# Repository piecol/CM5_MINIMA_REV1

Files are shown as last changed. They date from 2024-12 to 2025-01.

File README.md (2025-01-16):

# CM5_MINIMA_REV1
_Compact, feature-filled, CM5 LoRaWAN carrier board_

## **OSHWA**:
This project is certified as open-source hardware under the UID: IT000019
https://certification.oshwa.org/it000019.html

## **Warning**:
Board tested, everything works, except for the RAK3172 UART, which was moved from UART0_IR to UART2. It works with this change, schematics, layout and production files are corrected.

_Proceed at your own risk._

 [PDF SCHEMATICS](https://github.com/piecol/CM5_MINIMA_REV1/blob/main/CM5_MINIMA.pdf)

## **Peripherals**:
- USB-C PD (CM5 can negotiate power delivery!)
- USB2.0 
- Gigabit Ethernet with cutout magjack for low profile
- HDMI port
- RAK3172 lorawan chip from RAKwireless
- SHTC3 Sensirion temperature and humidity sensor
- I2C connector (3V3 only)
- Fan connector
- Various status LEDs
- Compact size 5.4 x 5.7 cm

## **Stackup**:
4L (SIG:PWR | GND | GND | SIG:PWR) 
JLC0416H-3313 impedance stackup

### If you would like to support me:

"Buy Me A Coffee" (https://www.buymeacoffee.com/pierluigicj)

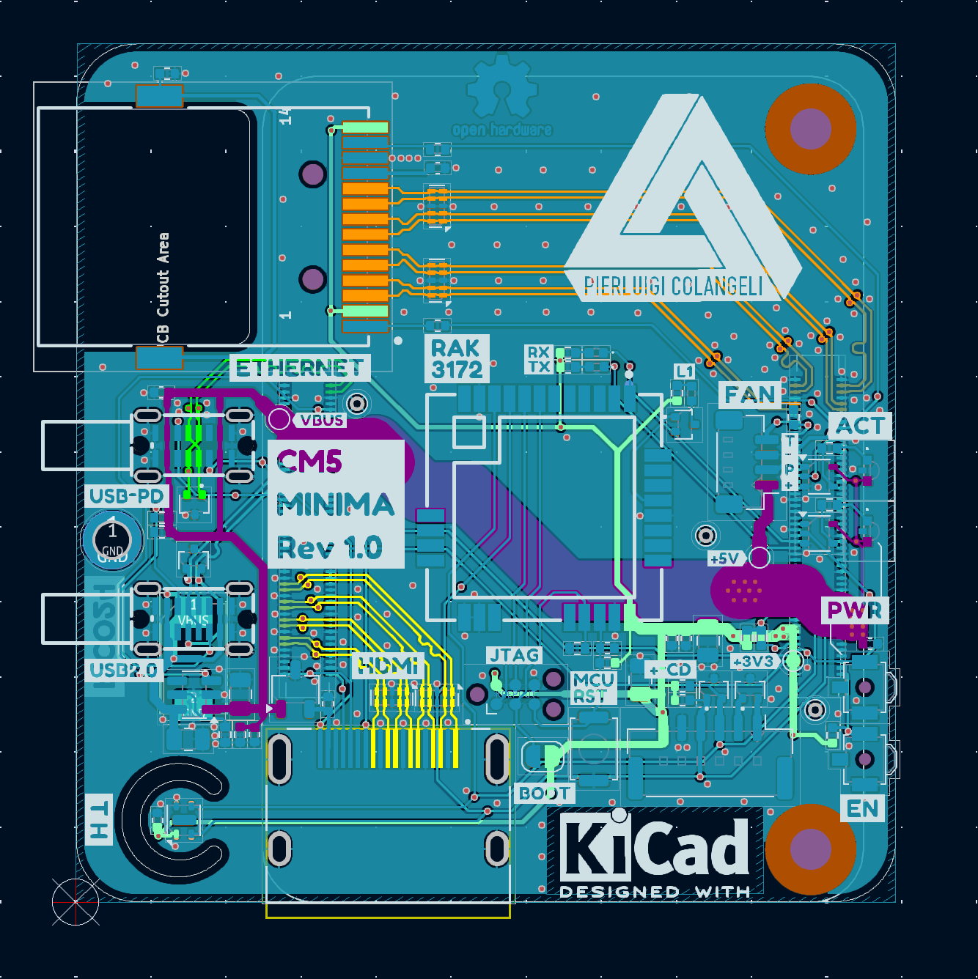
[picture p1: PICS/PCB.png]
PCB
 
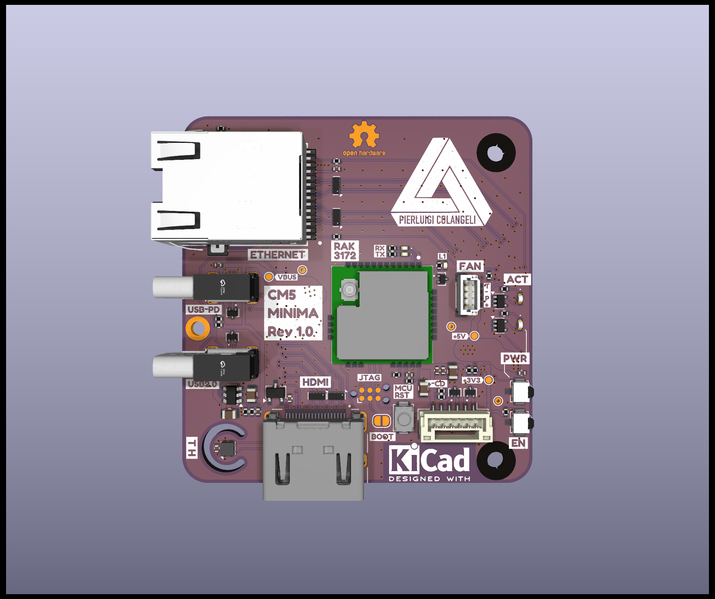
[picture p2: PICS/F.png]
F
 
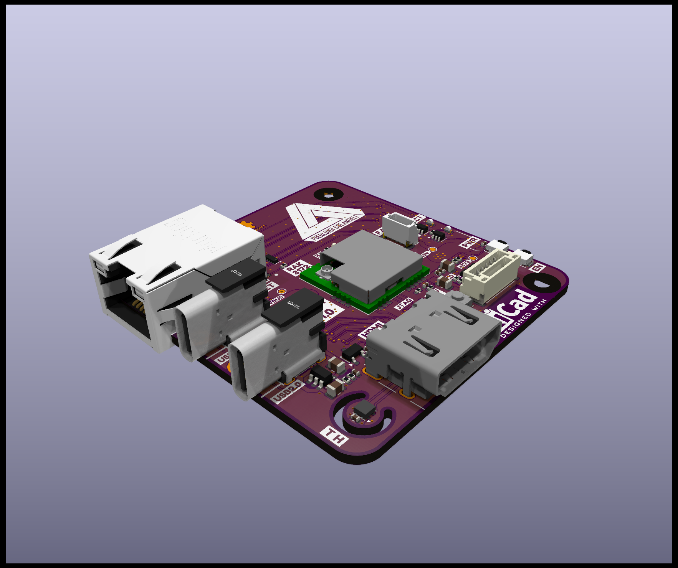
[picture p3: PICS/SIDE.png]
SIDE
 
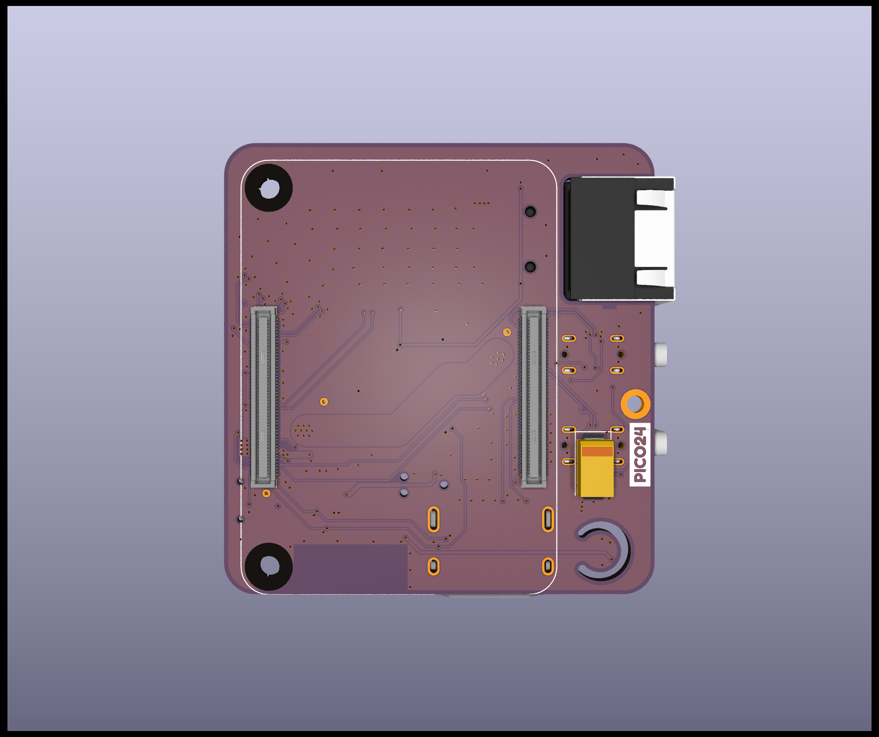
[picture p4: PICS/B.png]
B


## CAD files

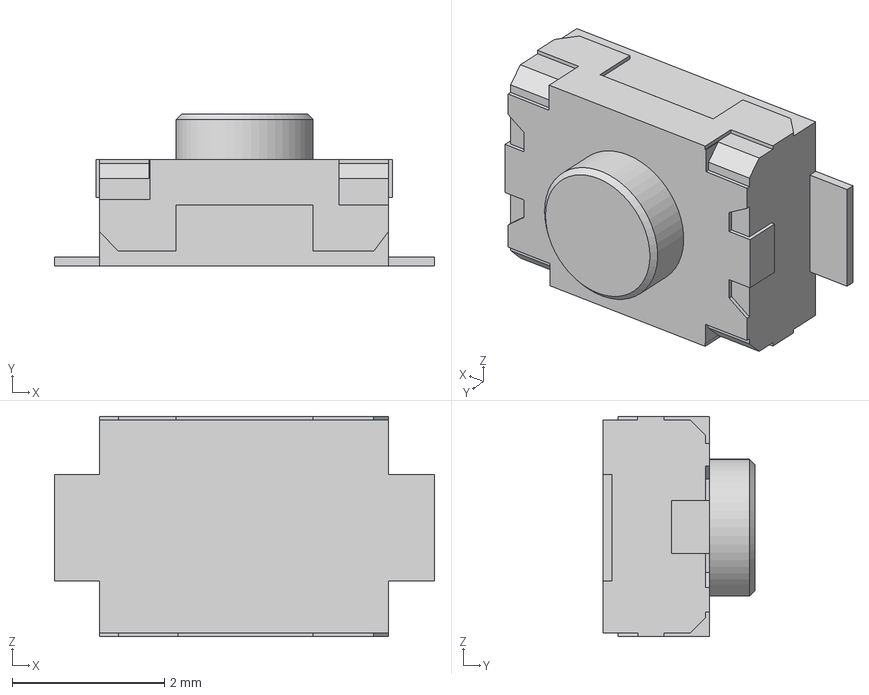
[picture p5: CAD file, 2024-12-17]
3d_lib/3x4x2 tact button.step
5.00 x 2.00 x 2.90 mm

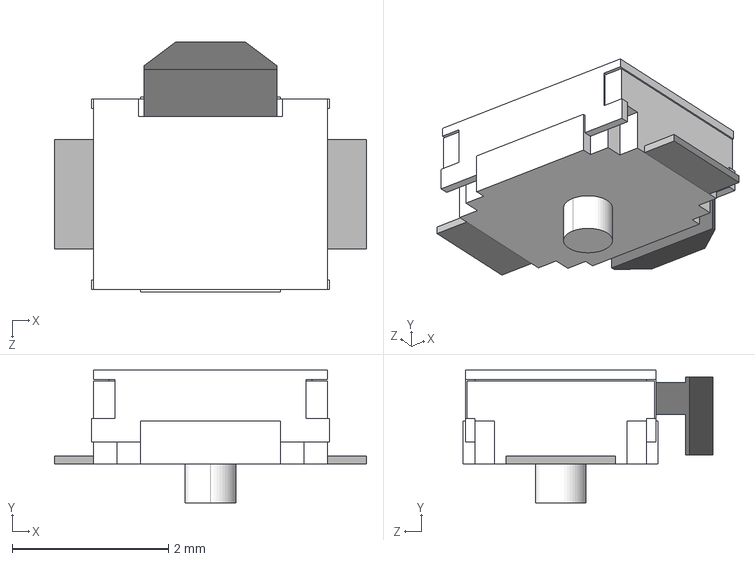
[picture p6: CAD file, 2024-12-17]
3d_lib/LIB_B3U-3000PM-B/B3U-3000PM-B/3D/B3U-3000PM-B.stp
4.00 x 1.70 x 3.20 mm

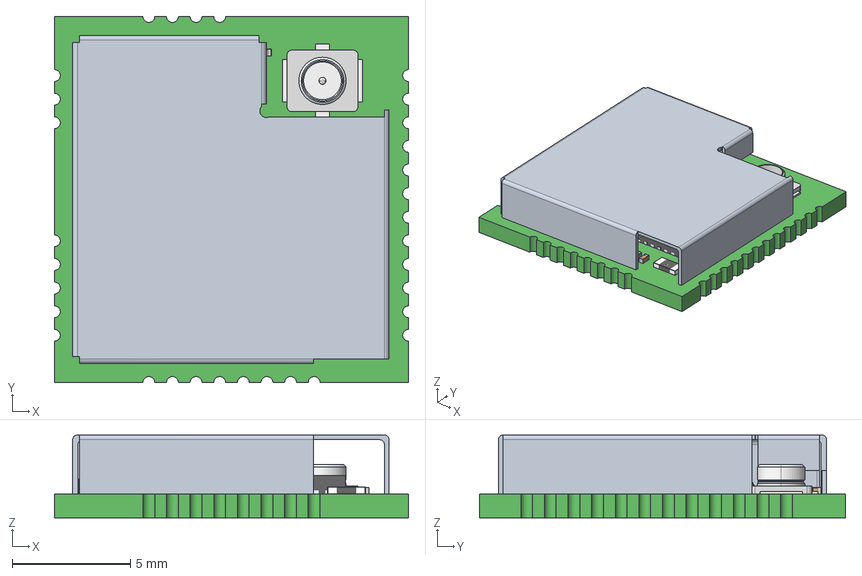
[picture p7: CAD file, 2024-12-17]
3d_lib/RAK3172--3DModel-STEP-100311.STEP
15.0 x 15.5 x 3.51 mm
0201_SMD_Capacitor x 36
Extruded
R0201 x 7
RES_1005-0402 x 3
QFN48_7x7
NT2016SA
C0402 x 4
crystal_rtf2012
D030A-そ敖裔

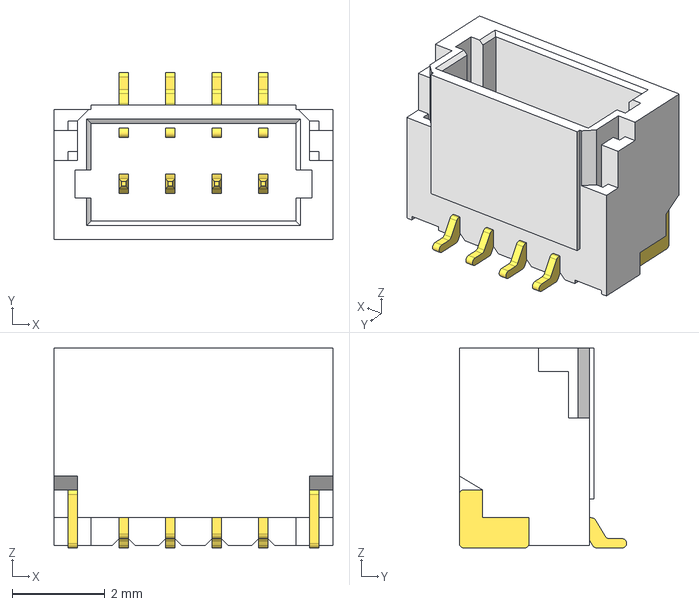
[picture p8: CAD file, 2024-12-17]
3d_lib/BM4B-SRSS-TB.step
6.00 x 3.60 x 4.30 mm

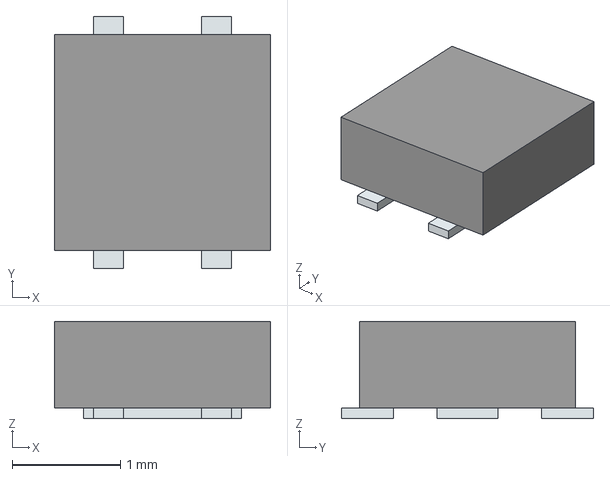
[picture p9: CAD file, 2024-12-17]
3d_lib/SHTC3-TR-10KS.stp
2.00 x 2.33 x 0.9 mm
Pins

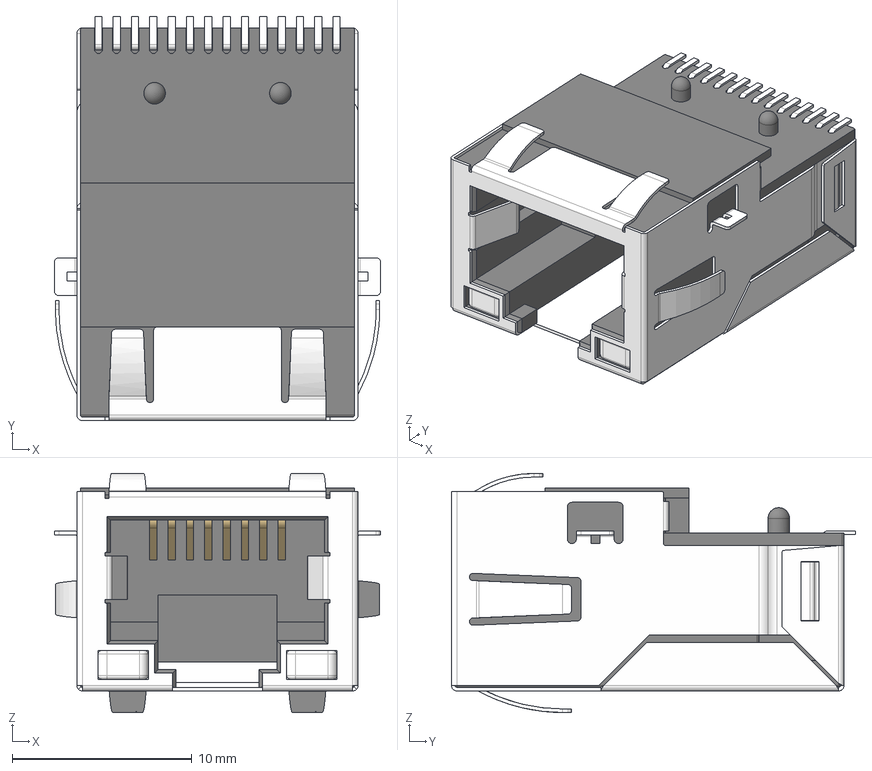
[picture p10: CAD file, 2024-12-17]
3d_lib/WE-RJ45LAN-7498111120AR (rev1).stp
18.1 x 22.5 x 13.3 mm
Shielding
Insulator x 3

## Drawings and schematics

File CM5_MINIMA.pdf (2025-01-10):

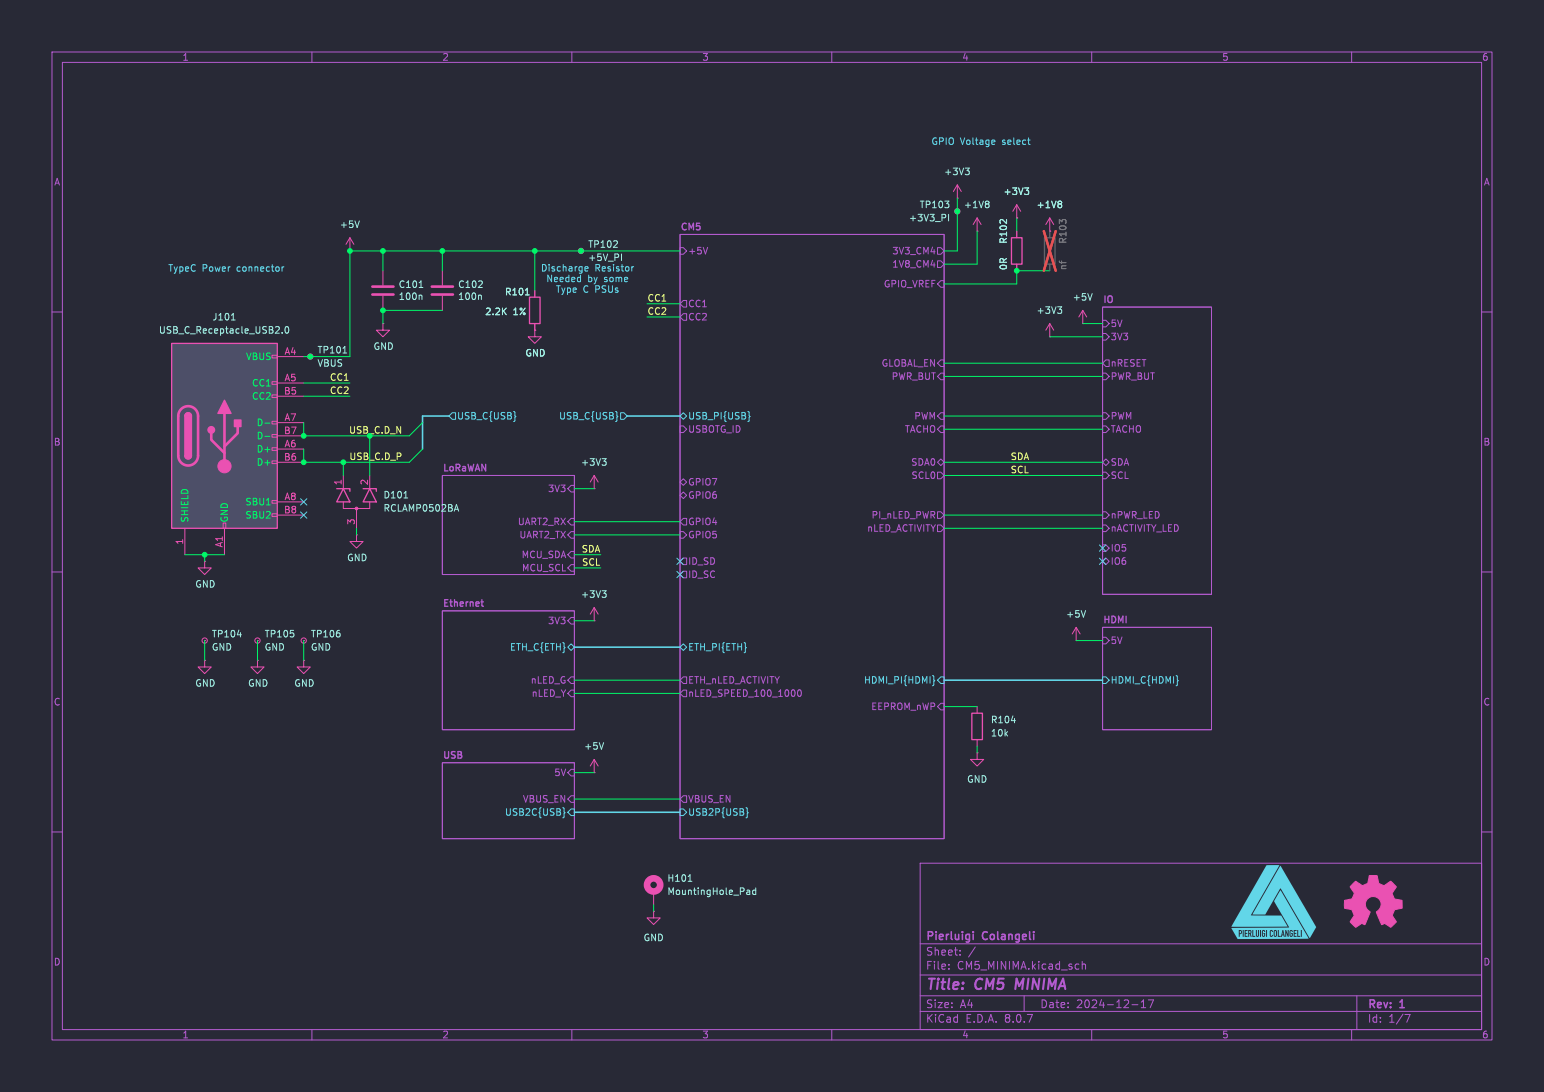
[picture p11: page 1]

File: CM5_MINIMA.kicad_sch Sheet: / Pierluigi Colangeli

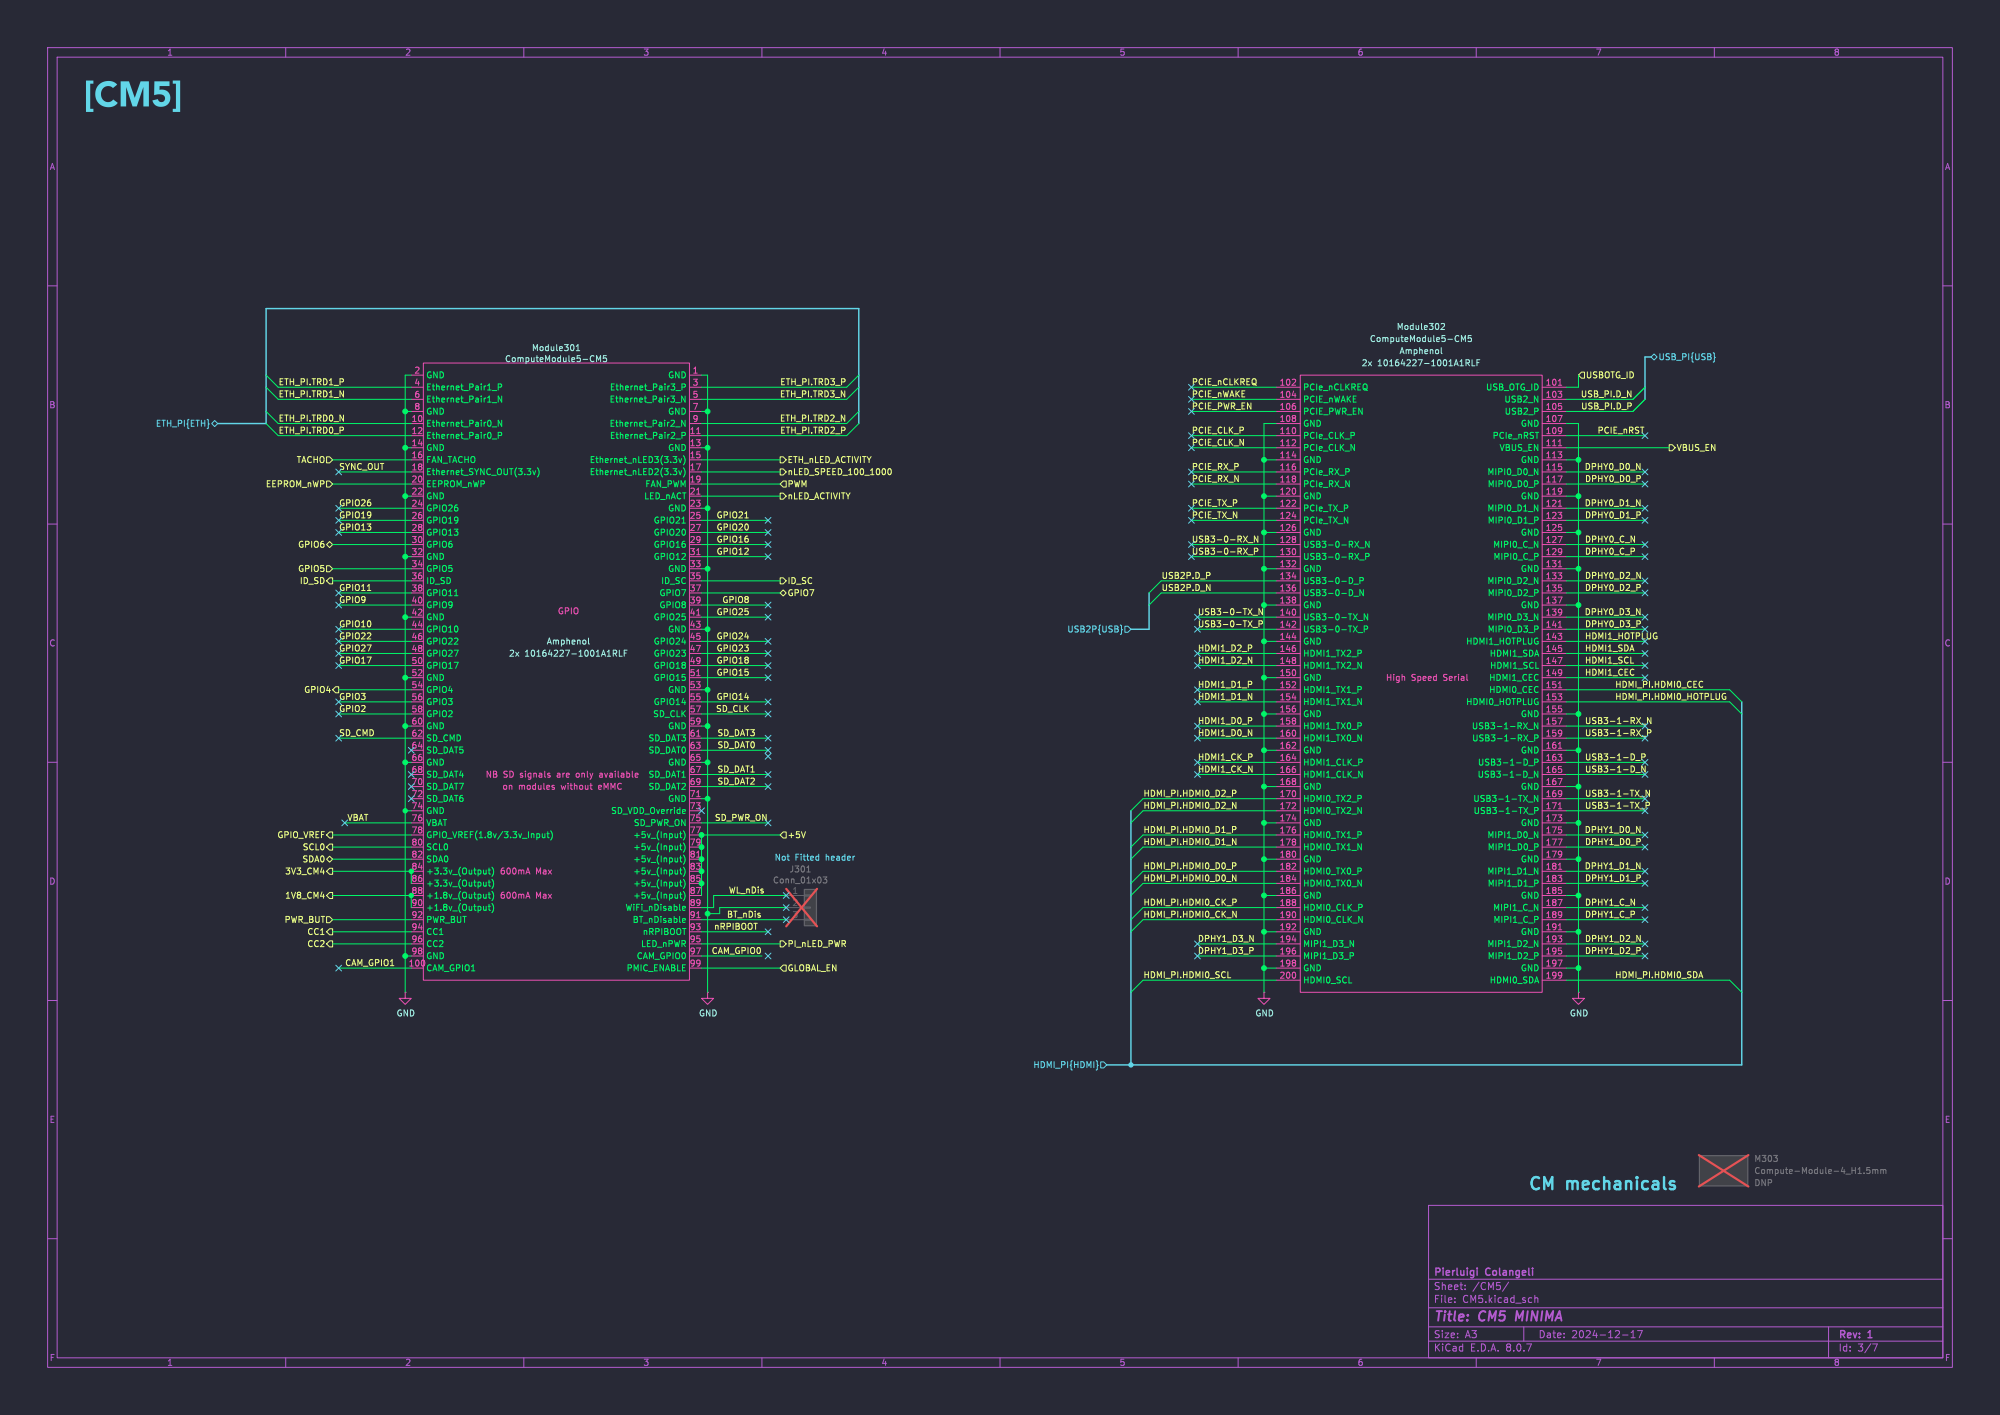
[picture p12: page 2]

600mA Max 600mA Max NB SD signals are only available

File: CM5.kicad_sch Sheet: /CM5/ Pierluigi Colangeli

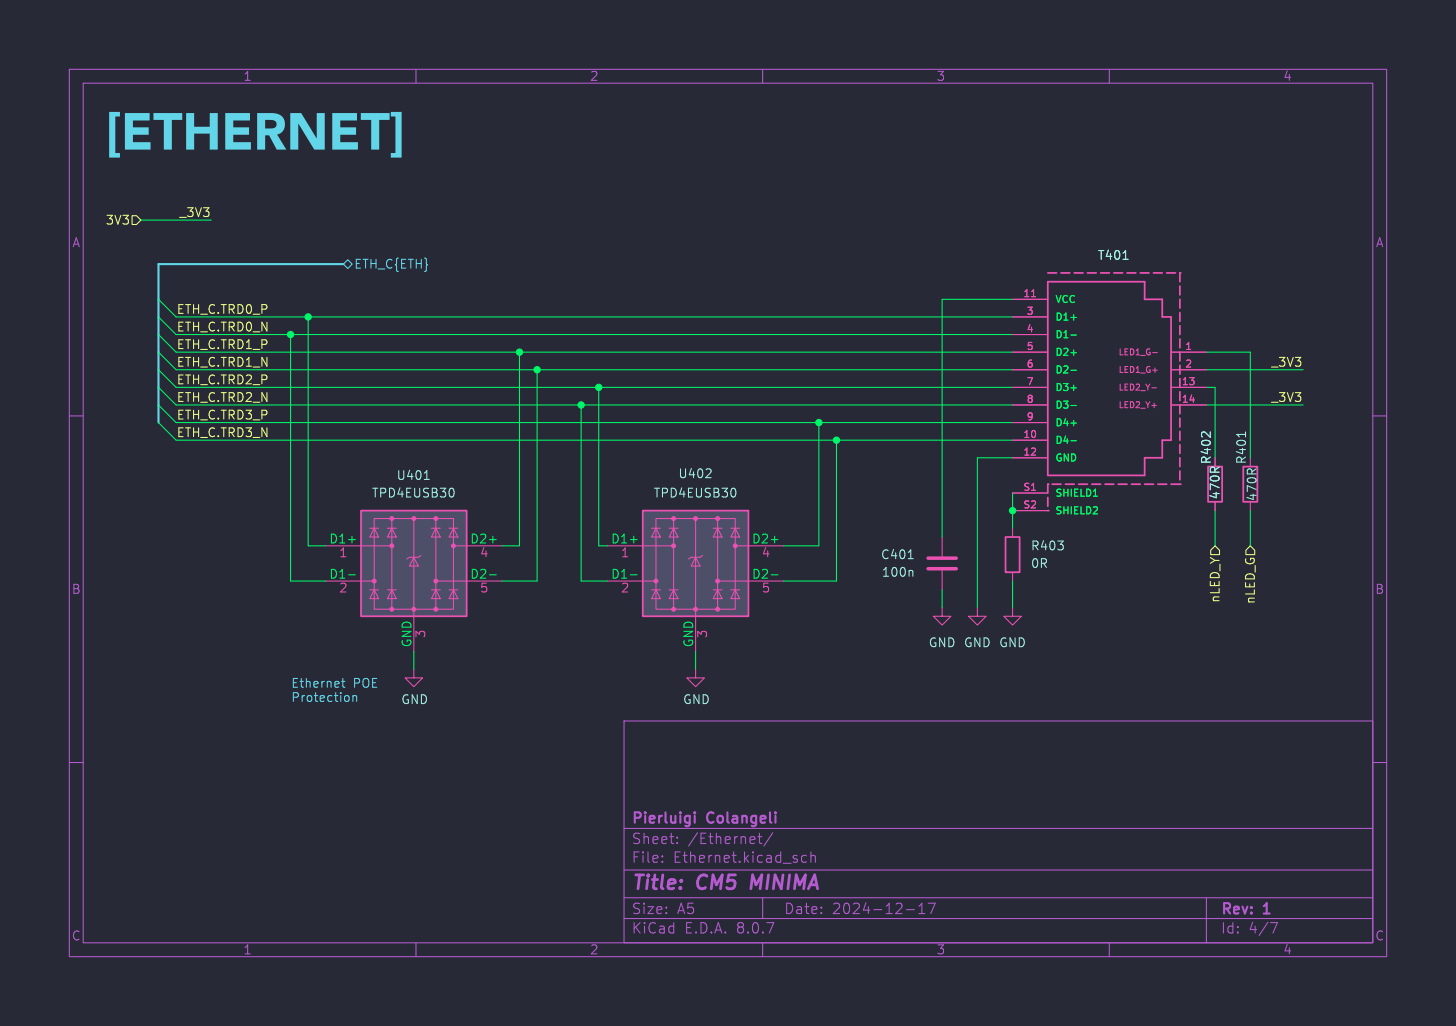
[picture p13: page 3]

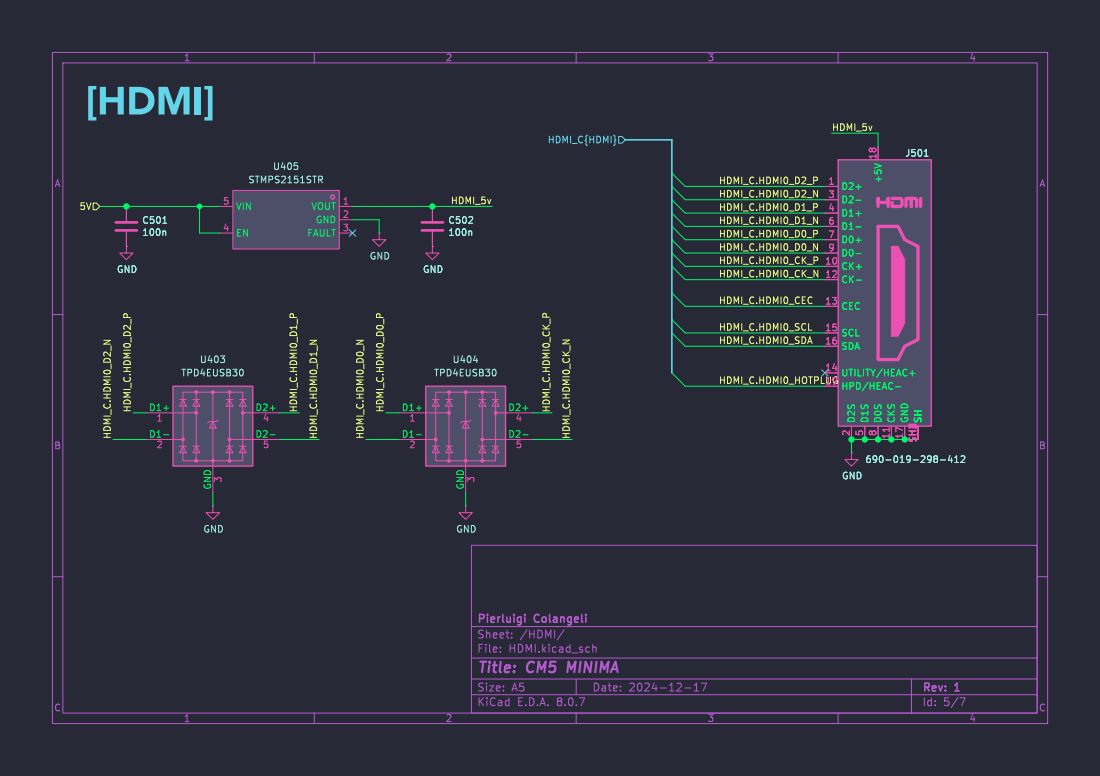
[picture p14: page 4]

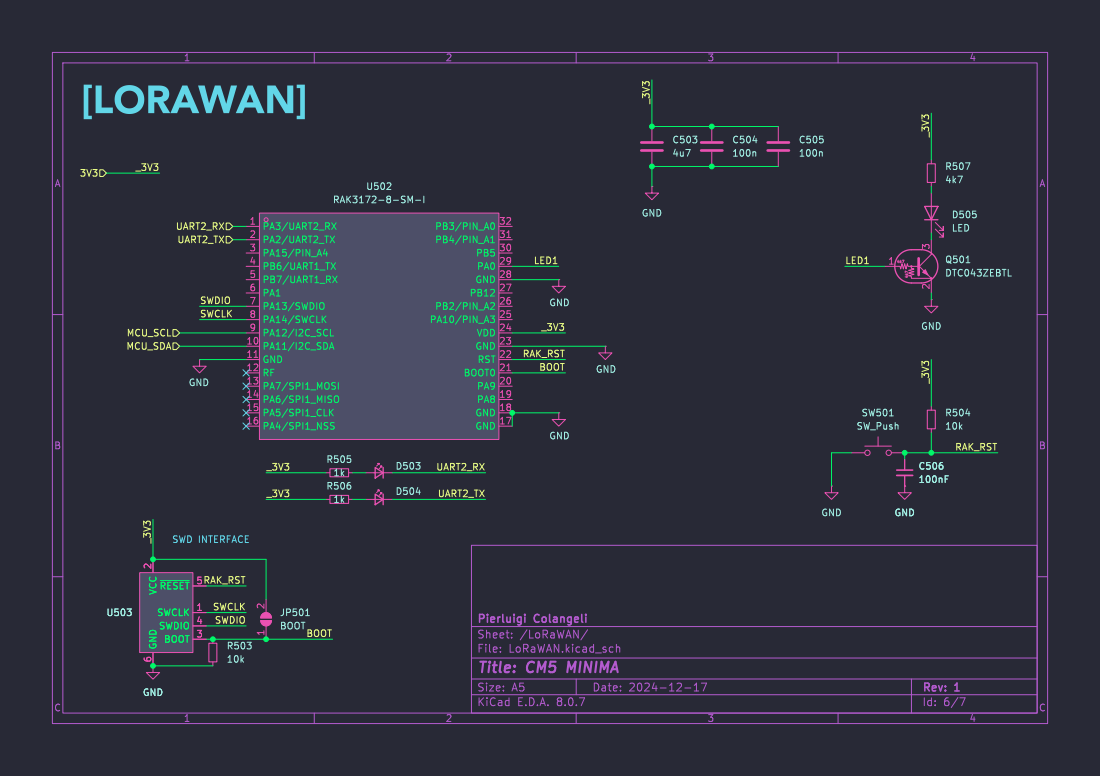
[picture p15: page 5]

2 BOOT 3 SWDIO 4 ~{RESET}5 GND

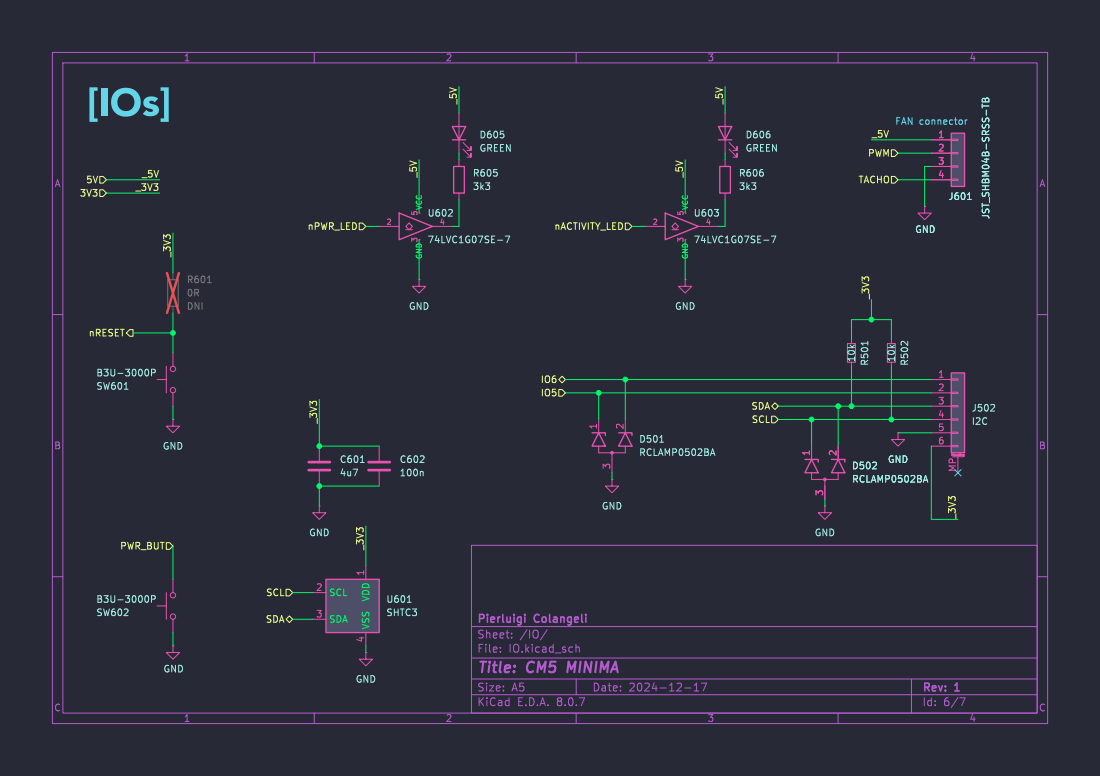
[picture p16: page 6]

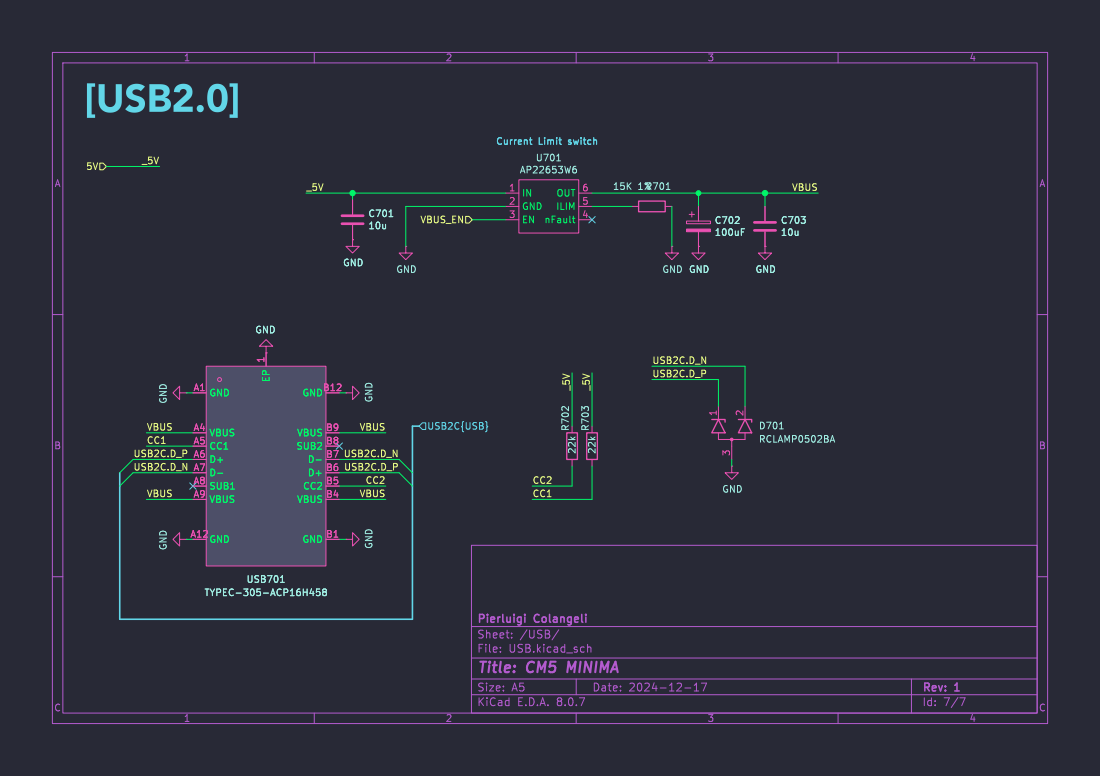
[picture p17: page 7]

1 GND A1 GND A12 VBUS A4 CC1 A5 D+ A6 D- A7 SUB1 A8 VBUS A9 GND B1 GNDB12 VBUS B4 CC2 B5 D+ B6 D- B7 SUB2 B8 VBUS B9 C701

1 GND A1 GND A12 VBUS A4 CC1 A5 D+ A6 D- A7 SUB1 A8 VBUS A9 GND B1 GNDB12 VBUS B4 CC2 B5 D+ B6 D- B7 SUB2 B8 VBUS B9 USB701 TYPEC-305-ACP16H458

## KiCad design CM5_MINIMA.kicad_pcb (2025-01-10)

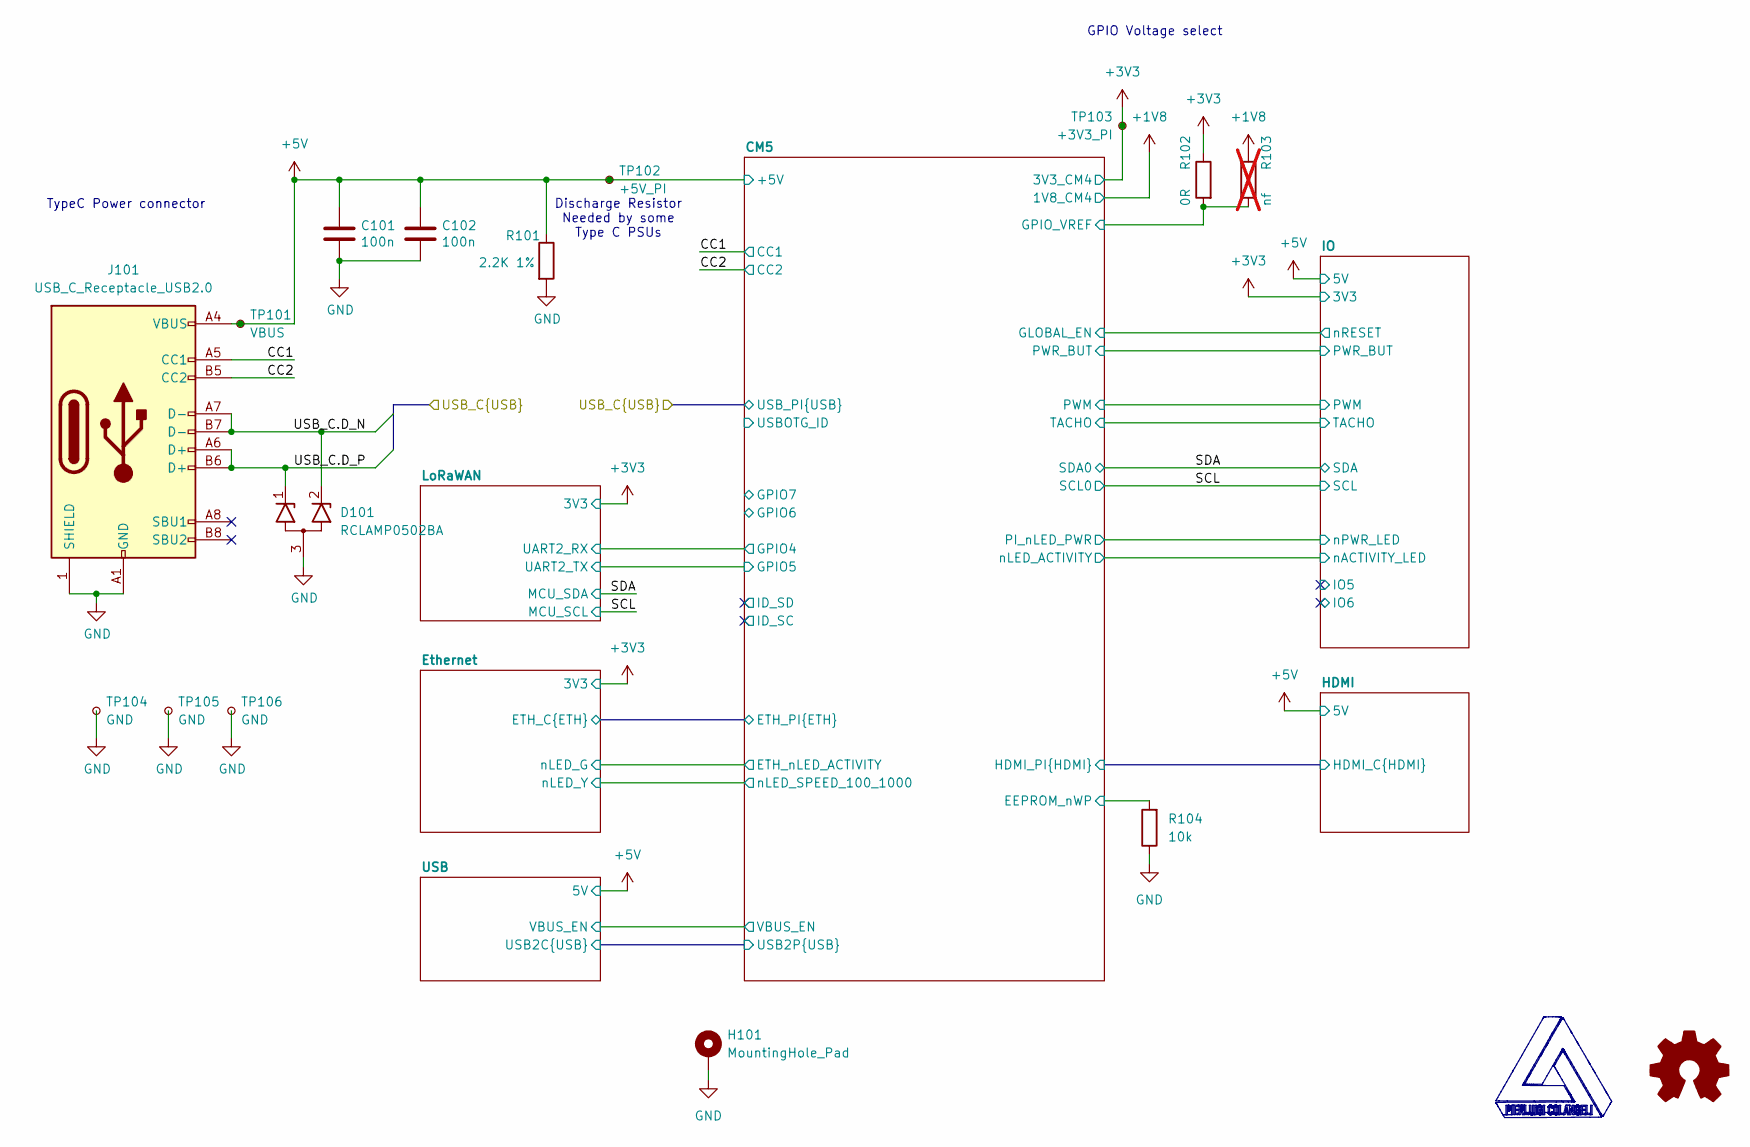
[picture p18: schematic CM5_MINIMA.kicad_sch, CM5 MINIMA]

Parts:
C101, C102: 100n; C_0402_1005Metric; Part Description 0.1uF 10% 16V Ceramic Capacitor X7R 040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
D101: RCLAMP0502BA; SOT-416
H101: MountingHole_Pad; MountingHole_2.2mm_M2_DIN965_Pad_TopBottom
J101: USB_C_Receptacle_USB2.0; USB-C-SMD_TYPEC-305-ACP16H458; Part Description USBC USB2 data and power connector
R101: 2.2K 1%; R_0402_1005Metric; Part Description Resistor 2.2K M1005 1% 63mW
R102: 0R; R_0402_1005Metric; Part Description Resistor 0R M2012 5%
R103: nf; R_0402_1005Metric; not fitted
R104: 10k; R_0402_1005Metric
TP101: VBUS; TestPoint_Pad_D1.0mm
TP102: +5V_PI; TestPoint_Pad_D1.0mm
TP103: +3V3_PI; TestPoint_Pad_D1.0mm
TP104, TP105, TP106: GND; TestPoint_THTPad_D1.0mm_Drill0.5mm

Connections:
+1V8: R103.1; also elsewhere on the board
+3V3: R102.1, TP103.1; also elsewhere on the board
+5V: C101.1, C102.1, J101.A4 (VBUS), J101.A9 (VBUS), J101.B4 (VBUS), J101.B9 (VBUS), R101.1, TP101.1, TP102.1; also elsewhere on the board
/CC1: J101.A5 (CC1); also elsewhere on the board
/CC2: J101.B5 (CC2); also elsewhere on the board
/CM5/EEPROM_nWP: R104.2; also elsewhere on the board
/CM5/GPIO_VREF: R102.2, R103.2; also elsewhere on the board
/USB_C.D_N: D101.2 (K2), J101.A7 (D-), J101.B7 (D-); also elsewhere on the board
/USB_C.D_P: D101.1 (K1), J101.A6 (D+), J101.B6 (D+); also elsewhere on the board
GND: C101.2, C102.2, D101.3 (A), H101.1, J101.1 (SHIELD), J101.A1 (GND), J101.A12 (GND), J101.B1 (GND), J101.B12 (GND), R101.2, R104.1, TP104.1, TP105.1, TP106.1; also elsewhere on the board

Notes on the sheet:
GPIO Voltage select
TypeC Power connector
Discharge Resistor Needed by some Type C PSUs

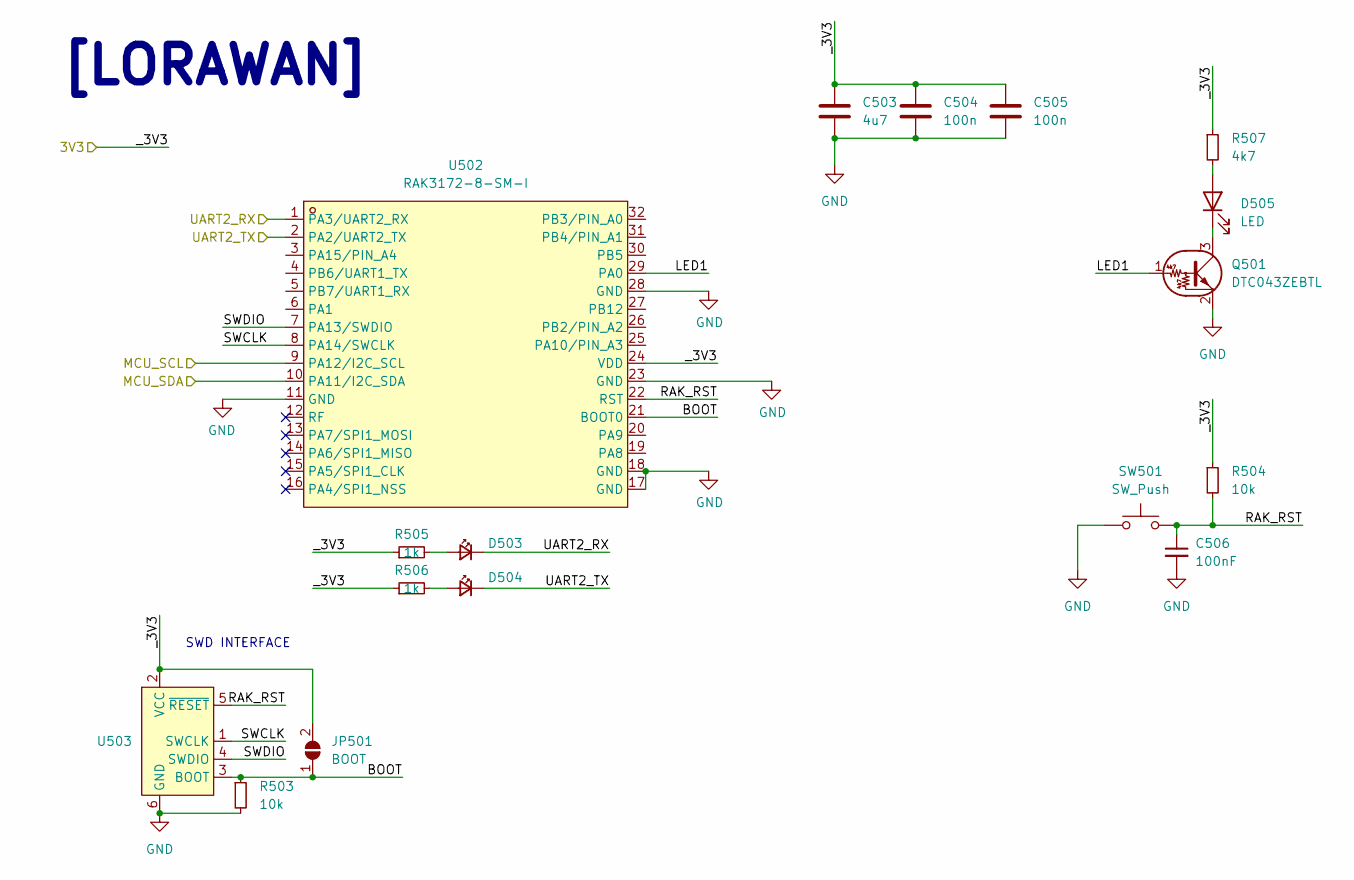
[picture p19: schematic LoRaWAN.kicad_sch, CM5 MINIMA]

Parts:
C503: 4u7; C_0805_2012Metric; Part Description 4.7uF 10% 10V Ceramic Capacitor X7R 080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
C504, C505: 100n; C_0402_1005Metric; Part Description 0.1uF 10% 16V Ceramic Capacitor X7R 040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
C506: 100nF; C_0402_1005Metric
D503, D504: CHRG; LED_0402_1005Metric
D505: LED; LED_0402_1005Metric
JP501: BOOT; SolderJumper-2_P1.3mm_Open_RoundedPad1.0x1.5mm
Q501: DTC043ZEBTL; SOT-416
R503, R504: 10k; R_0402_1005Metric
R505, R506: 1k; R_0402_1005Metric
R507: 4k7; R_0402_1005Metric
SW501: SW_Push; SW_Push_SPST_NO_Alps_SKRK
U502: RAK3172-8-SM-I; WIRELM-SMD_32P-L15.5-W15.0-P1.00; LCSC Part C19723904
U503: Tag-Connect_TC2030-IDC-NL_2x03_P1.27mm_Vertical

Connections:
+3V3: C503.1, C504.1, C505.1, JP501.2 (B), R504.1, R505.1, R506.1, R507.1, U502.24 (VDD), U503.2 (VCC); also elsewhere on the board
/LoRaWAN/BOOT: JP501.1 (A), R503.1, U502.21 (BOOT0), U503.3 (BOOT)
/LoRaWAN/LED1: Q501.1 (B), U502.29 (PA0)
/LoRaWAN/RAK_RST: C506.1, R504.2, SW501.2, U502.22 (RST), U503.5 (~RESET)
/LoRaWAN/SWCLK: U502.8 (PA14/SWCLK), U503.1 (SWCLK)
/LoRaWAN/SWDIO: U502.7 (PA13/SWDIO), U503.4 (SWDIO)
/LoRaWAN/UART2_RX: D503.1 (K), U502.1 (PA3/UART2_RX); also elsewhere on the board
/LoRaWAN/UART2_TX: D504.1 (K), U502.2 (PA2/UART2_TX); also elsewhere on the board
/SCL: U502.9 (PA12/I2C_SCL); also elsewhere on the board
/SDA: U502.10 (PA11/I2C_SDA); also elsewhere on the board
GND: C503.2, C504.2, C505.2, C506.2, Q501.2 (E), R503.2, SW501.1, U502.11 (GND), U502.17 (GND), U502.18 (GND), U502.23 (GND), U502.28 (GND), U503.6 (GND); also elsewhere on the board
unnamed: D503.2 (A), R505.2
unnamed: D504.2 (A), R506.2
unnamed: D505.2 (A), R507.2
unnamed: D505.1 (K), Q501.3 (C)

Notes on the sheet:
[LORAWAN]
SWD INTERFACE

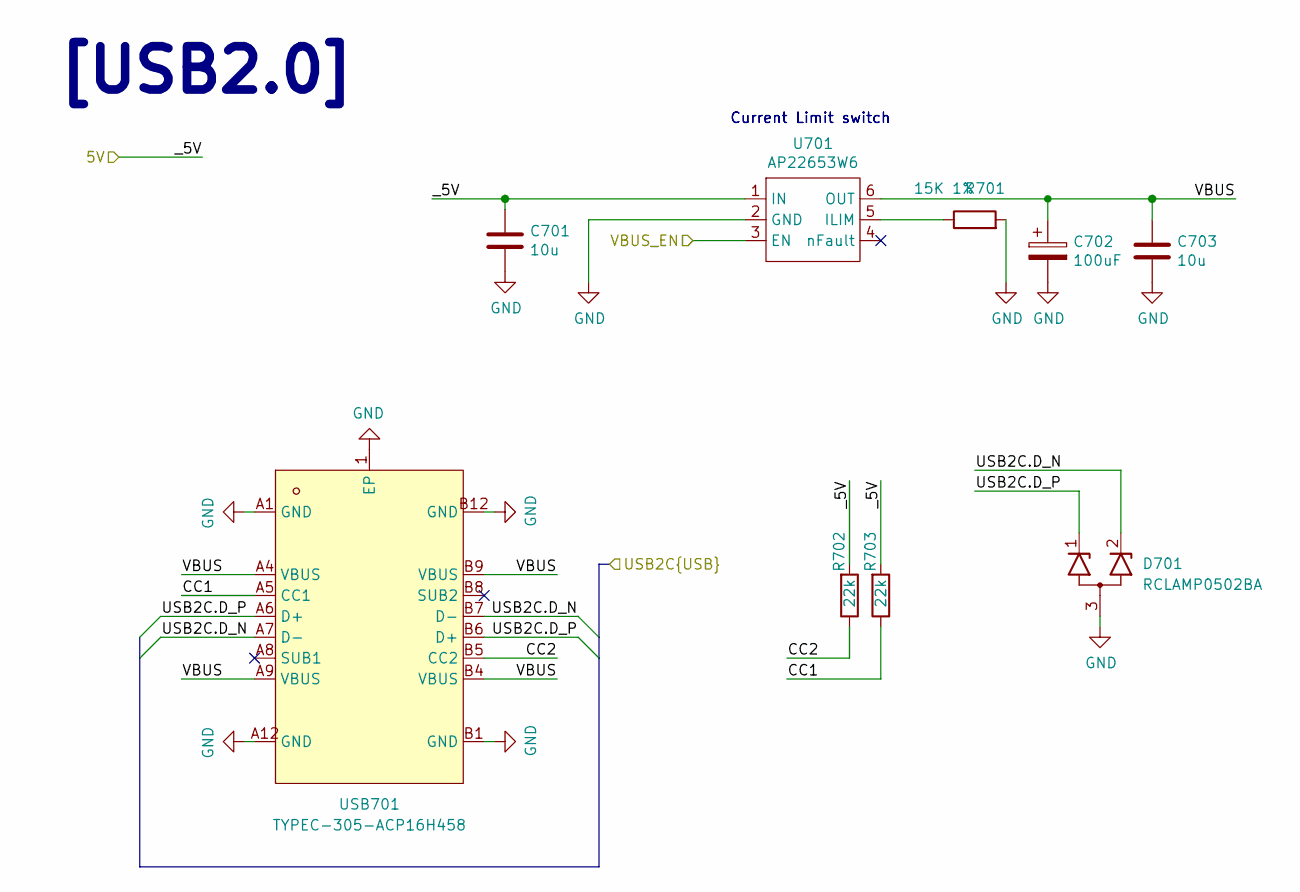
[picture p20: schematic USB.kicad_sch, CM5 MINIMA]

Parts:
C701, C703: 10u; C_0805_2012Metric; Part Description 10uF 10% 10V Ceramic Capacitor X7R 0805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
C702: 100uF; CP_EIA-7343-31_Kemet-D; Part Description Capacitor, SP-Cap, 100u, 6.3V, 15mR ESR
D701: RCLAMP0502BA; SOT-416
R701: 15K 1%; R_0402_1005Metric; Part Description Resistor 15K M1005 1% 63mW
R702, R703: 22k; R_0402_1005Metric
U701: AP22653W6; SOT-23-6; Part Description Power Switch/Driver 1:1 P-Channel 2.1A 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
USB701: TYPEC-305-ACP16H458; USB-C-SMD_TYPEC-305-ACP16H458; LCSC Part C5454943

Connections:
+5V: C701.1, R702.2, R703.2, U701.1 (IN); also elsewhere on the board
/CM5/USB2P.D_N: D701.2 (K2), USB701.A7 (D-), USB701.B7 (D-); also elsewhere on the board
/CM5/USB2P.D_P: D701.1 (K1), USB701.A6 (D+), USB701.B6 (D+); also elsewhere on the board
/CM5/VBUS_EN: U701.3 (EN); also elsewhere on the board
/USB/CC1: R703.1, USB701.A5 (CC1)
/USB/CC2: R702.1, USB701.B5 (CC2)
/USB/VBUS: C702.1, C703.1, U701.6 (OUT), USB701.A4 (VBUS), USB701.A9 (VBUS), USB701.B4 (VBUS), USB701.B9 (VBUS)
GND: C701.2, C702.2, C703.2, D701.3 (A), R701.2, U701.2 (GND), USB701.1 (EP), USB701.A1 (GND), USB701.A12 (GND), USB701.B1 (GND), USB701.B12 (GND); also elsewhere on the board
unnamed: R701.1, U701.5 (ILIM)

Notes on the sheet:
[USB2.0]
Current Limit switch

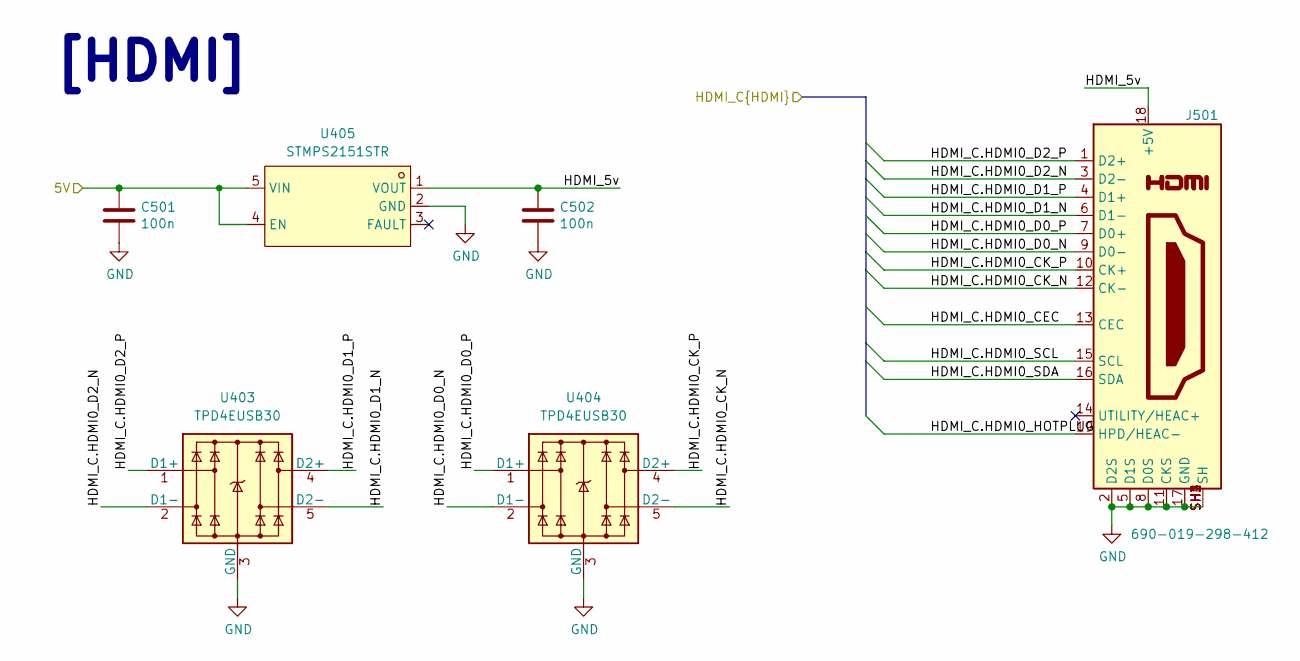
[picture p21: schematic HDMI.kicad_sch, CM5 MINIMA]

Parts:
C501, C502: 100n; C_0402_1005Metric; Part Description 0.1uF 10% 16V Ceramic Capacitor X7R 040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
J501: 690-019-298-412; EDAC 690-019-298-412; Part Description HDMI Connector, Right Angle, 19 Contact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
U403, U404: TPD4EUSB30; USON-10_2.5x1.0mm_P0.5mm; Part Description Quad TVS diode for high speed signals (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
U405: STMPS2151STR; SOT-23-5; LCSC Part C135998

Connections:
+5V: C501.1, U405.4 (EN), U405.5 (VIN); also elsewhere on the board
/CM5/HDMI_PI.HDMI0_CEC: J501.13 (CEC); also elsewhere on the board
/CM5/HDMI_PI.HDMI0_CK_N: J501.12 (CK-), U404.5 (D2-), U404.6; also elsewhere on the board
/CM5/HDMI_PI.HDMI0_CK_P: J501.10 (CK+), U404.4 (D2+), U404.7; also elsewhere on the board
/CM5/HDMI_PI.HDMI0_D0_N: J501.9 (D0-), U404.2 (D1-), U404.9; also elsewhere on the board
/CM5/HDMI_PI.HDMI0_D0_P: J501.7 (D0+), U404.1 (D1+), U404.10; also elsewhere on the board
/CM5/HDMI_PI.HDMI0_D1_N: J501.6 (D1-), U403.5 (D2-), U403.6; also elsewhere on the board
/CM5/HDMI_PI.HDMI0_D1_P: J501.4 (D1+), U403.4 (D2+), U403.7; also elsewhere on the board
/CM5/HDMI_PI.HDMI0_D2_N: J501.3 (D2-), U403.2 (D1-), U403.9; also elsewhere on the board
/CM5/HDMI_PI.HDMI0_D2_P: J501.1 (D2+), U403.1 (D1+), U403.10; also elsewhere on the board
/CM5/HDMI_PI.HDMI0_HOTPLUG: J501.19 (HPD/HEAC-); also elsewhere on the board
/CM5/HDMI_PI.HDMI0_SCL: J501.15 (SCL); also elsewhere on the board
/CM5/HDMI_PI.HDMI0_SDA: J501.16 (SDA); also elsewhere on the board
/HDMI/HDMI_5v: C502.1, J501.18 (+5V), U405.1 (VOUT)
GND: C501.2, C502.2, J501.2 (D2S), J501.5 (D1S), J501.8 (D0S), J501.11 (CKS), J501.17 (GND), J501.SH1 (SH), J501.SH2 (SH), J501.SH3 (SH), J501.SH4 (SH), U403.3 (GND), U403.8 (GND), U404.3 (GND), U404.8 (GND), U405.2 (GND); also elsewhere on the board

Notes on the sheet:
[HDMI]

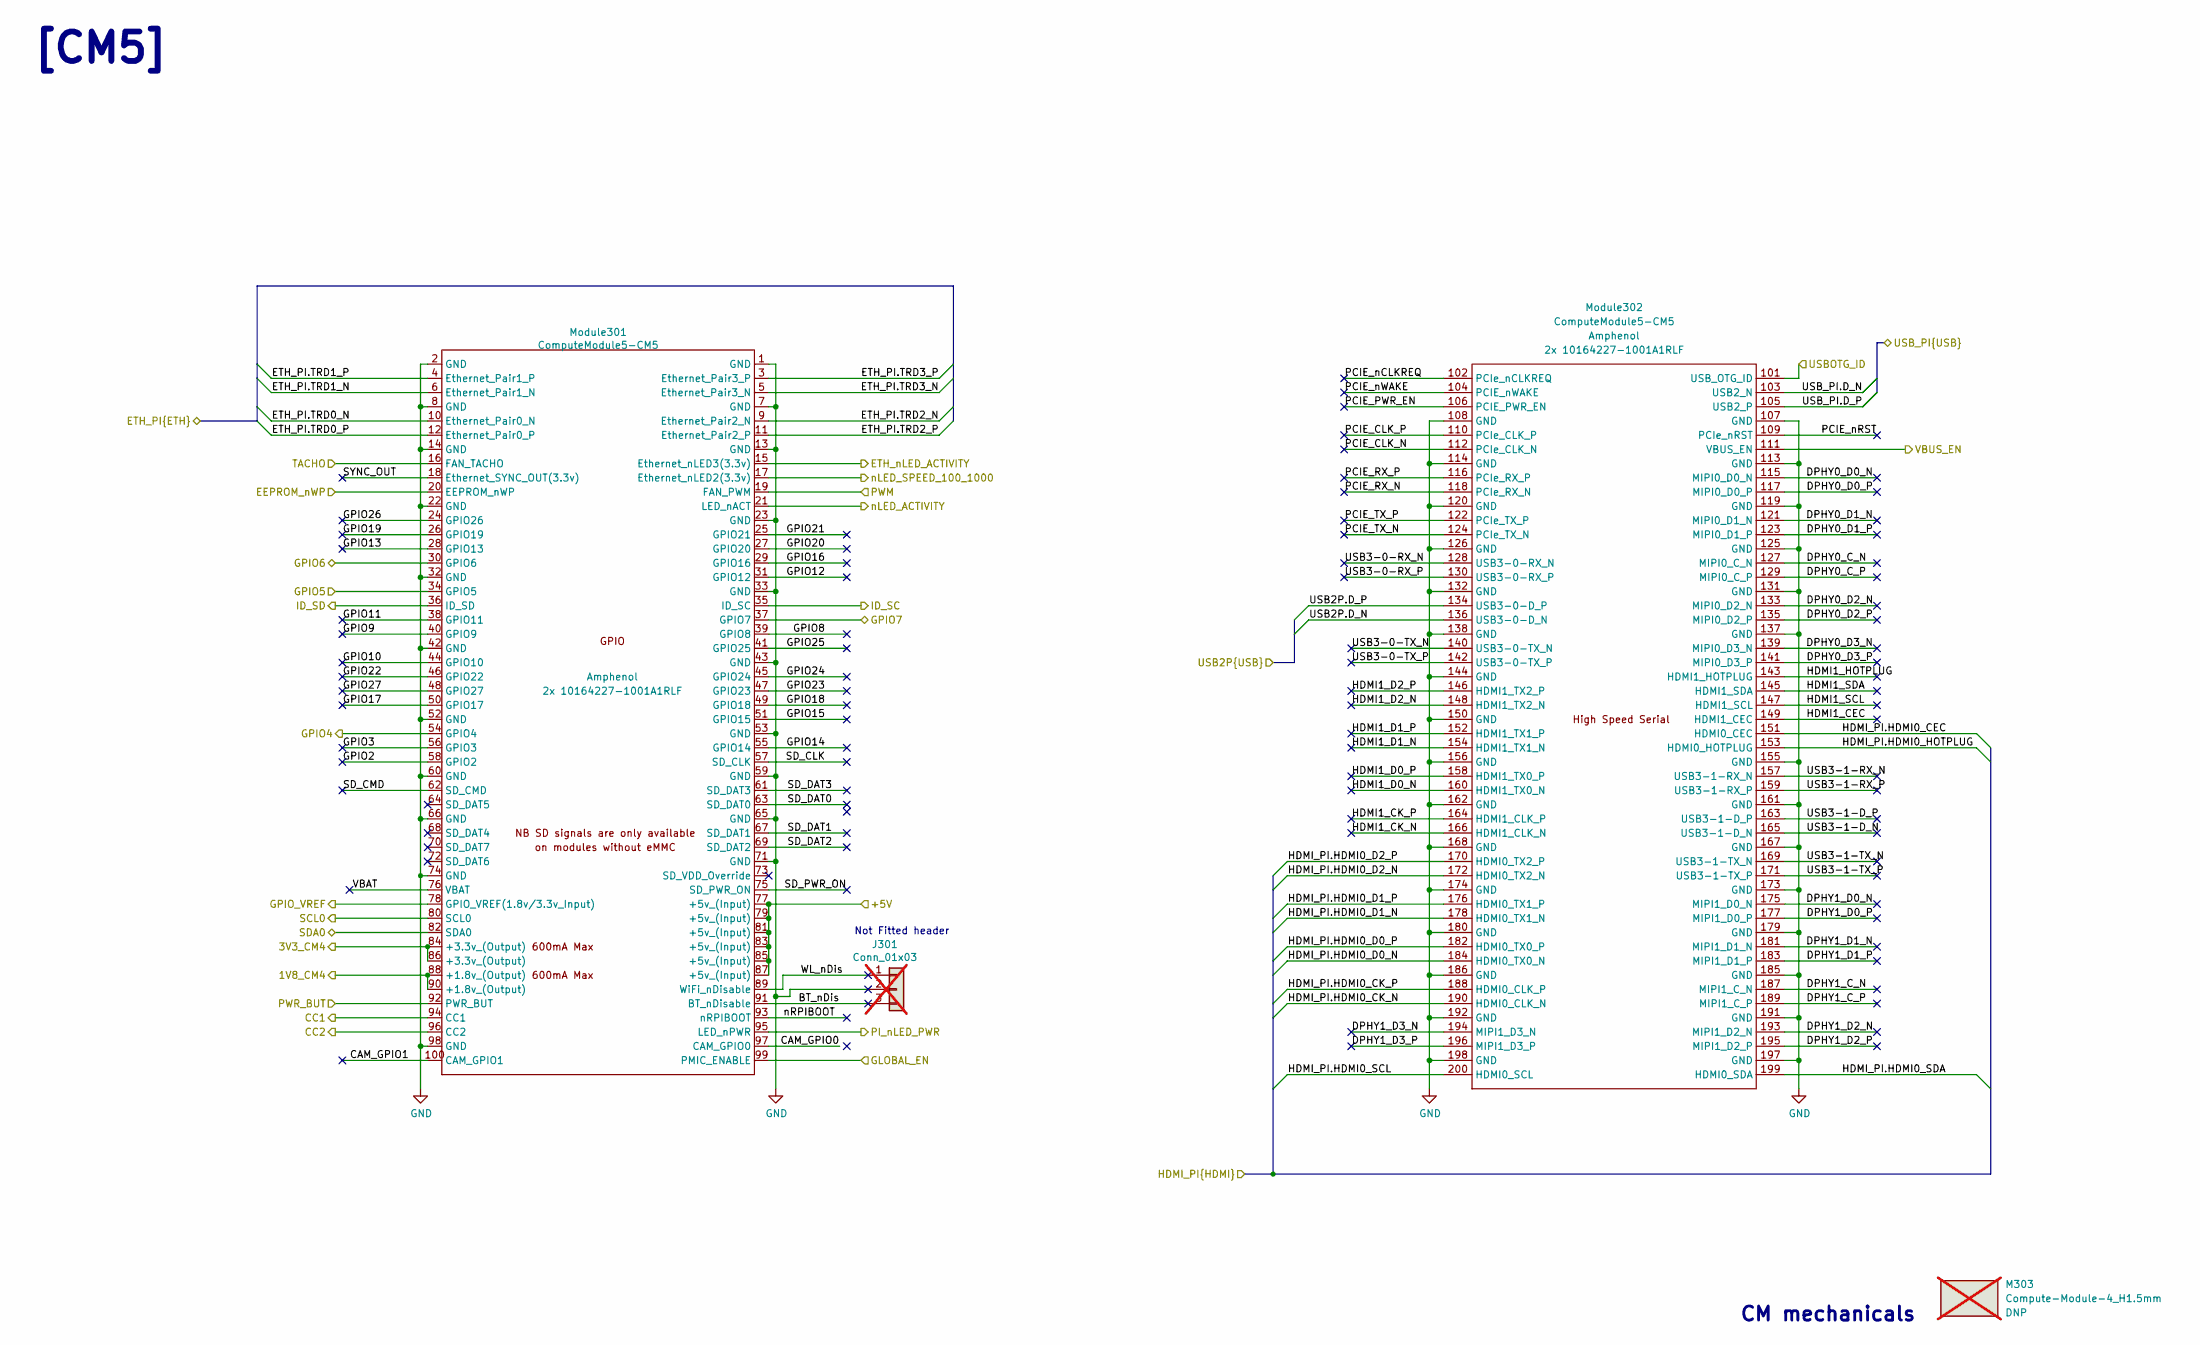
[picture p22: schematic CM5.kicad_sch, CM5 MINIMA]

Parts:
J301: Conn_01x03; PinHeader_1x03_P2.54mm_Vertical; Part Description 3pin 0.1" connector; not fitted
M303: Compute-Module-4_H1.5mm; MPN SC0294; not fitted
Module301: ComputeModule5-CM5; Raspberry-Pi-5-Compute-Module_GPIO; Part Description 100 Position Connector Receptacle, Cent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
Module302: ComputeModule5-CM5; Raspberry-Pi-5-Compute-Module_HSS; Part Description 100 Position Connector Receptacle, Cent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

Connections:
+1V8: Module301.88 (+1.8v_(Output)), Module301.90 (+1.8v_(Output)); also elsewhere on the board
+3V3: Module301.84 (+3.3v_(Output)), Module301.86 (+3.3v_(Output)); also elsewhere on the board
+5V: Module301.77 (+5v_(Input)), Module301.79 (+5v_(Input)), Module301.81 (+5v_(Input)), Module301.83 (+5v_(Input)), Module301.85 (+5v_(Input)), Module301.87 (+5v_(Input)); also elsewhere on the board
/CC1: Module301.94 (CC1); also elsewhere on the board
/CC2: Module301.96 (CC2); also elsewhere on the board
/CM5/BT_nDis: J301.3, Module301.91 (BT_nDisable)
/CM5/CAM_GPIO0: Module301.97 (CAM_GPIO0)
/CM5/CAM_GPIO1: Module301.100 (CAM_GPIO1)
/CM5/DPHY0_C_N: Module302.127 (MIPI0_C_N)
/CM5/DPHY0_C_P: Module302.129 (MIPI0_C_P)
/CM5/DPHY0_D0_N: Module302.115 (MIPI0_D0_N)
/CM5/DPHY0_D0_P: Module302.117 (MIPI0_D0_P)
/CM5/DPHY0_D1_N: Module302.121 (MIPI0_D1_N)
/CM5/DPHY0_D1_P: Module302.123 (MIPI0_D1_P)
/CM5/DPHY0_D2_N: Module302.133 (MIPI0_D2_N)
/CM5/DPHY0_D2_P: Module302.135 (MIPI0_D2_P)
/CM5/DPHY0_D3_N: Module302.139 (MIPI0_D3_N)
/CM5/DPHY0_D3_P: Module302.141 (MIPI0_D3_P)
/CM5/DPHY1_C_N: Module302.187 (MIPI1_C_N)
/CM5/DPHY1_C_P: Module302.189 (MIPI1_C_P)
/CM5/DPHY1_D0_N: Module302.175 (MIPI1_D0_N)
/CM5/DPHY1_D0_P: Module302.177 (MIPI1_D0_P)
/CM5/DPHY1_D1_N: Module302.181 (MIPI1_D1_N)
/CM5/DPHY1_D1_P: Module302.183 (MIPI1_D1_P)
/CM5/DPHY1_D2_N: Module302.193 (MIPI1_D2_N)
/CM5/DPHY1_D2_P: Module302.195 (MIPI1_D2_P)
/CM5/DPHY1_D3_N: Module302.194 (MIPI1_D3_N)
/CM5/DPHY1_D3_P: Module302.196 (MIPI1_D3_P)
/CM5/EEPROM_nWP: Module301.20 (EEPROM_nWP); also elsewhere on the board
/CM5/ETH_PI.TRD0_N: Module301.10 (Ethernet_Pair0_N); also elsewhere on the board
/CM5/ETH_PI.TRD0_P: Module301.12 (Ethernet_Pair0_P); also elsewhere on the board
/CM5/ETH_PI.TRD1_N: Module301.6 (Ethernet_Pair1_N); also elsewhere on the board
/CM5/ETH_PI.TRD1_P: Module301.4 (Ethernet_Pair1_P); also elsewhere on the board
/CM5/ETH_PI.TRD2_N: Module301.9 (Ethernet_Pair2_N); also elsewhere on the board
/CM5/ETH_PI.TRD2_P: Module301.11 (Ethernet_Pair2_P); also elsewhere on the board
/CM5/ETH_PI.TRD3_N: Module301.5 (Ethernet_Pair3_N); also elsewhere on the board
/CM5/ETH_PI.TRD3_P: Module301.3 (Ethernet_Pair3_P); also elsewhere on the board
/CM5/ETH_nLED_ACTIVITY: Module301.15 (Ethernet_nLED3(3.3v)); also elsewhere on the board
/CM5/GLOBAL_EN: Module301.99 (PMIC_ENABLE); also elsewhere on the board
/CM5/GPIO2: Module301.58 (GPIO2)
/CM5/GPIO3: Module301.56 (GPIO3)
/CM5/GPIO6: Module301.30 (GPIO6)
/CM5/GPIO7: Module301.37 (GPIO7)
/CM5/GPIO8: Module301.39 (GPIO8)
/CM5/GPIO9: Module301.40 (GPIO9)
/CM5/GPIO10: Module301.44 (GPIO10)
/CM5/GPIO11: Module301.38 (GPIO11)
/CM5/GPIO12: Module301.31 (GPIO12)
/CM5/GPIO13: Module301.28 (GPIO13)
/CM5/GPIO14: Module301.55 (GPIO14)
/CM5/GPIO15: Module301.51 (GPIO15)
/CM5/GPIO16: Module301.29 (GPIO16)
/CM5/GPIO17: Module301.50 (GPIO17)
/CM5/GPIO18: Module301.49 (GPIO18)
/CM5/GPIO19: Module301.26 (GPIO19)
/CM5/GPIO20: Module301.27 (GPIO20)
/CM5/GPIO21: Module301.25 (GPIO21)
/CM5/GPIO22: Module301.46 (GPIO22)
/CM5/GPIO23: Module301.47 (GPIO23)
/CM5/GPIO24: Module301.45 (GPIO24)
/CM5/GPIO25: Module301.41 (GPIO25)
/CM5/GPIO26: Module301.24 (GPIO26)
/CM5/GPIO27: Module301.48 (GPIO27)
/CM5/GPIO_VREF: Module301.78 (GPIO_VREF(1.8v/3.3v_Input)); also elsewhere on the board
/CM5/HDMI1_CEC: Module302.149 (HDMI1_CEC)
/CM5/HDMI1_CK_N: Module302.166 (HDMI1_CLK_N)
/CM5/HDMI1_CK_P: Module302.164 (HDMI1_CLK_P)
/CM5/HDMI1_D0_N: Module302.160 (HDMI1_TX0_N)
/CM5/HDMI1_D0_P: Module302.158 (HDMI1_TX0_P)
/CM5/HDMI1_D1_N: Module302.154 (HDMI1_TX1_N)
/CM5/HDMI1_D1_P: Module302.152 (HDMI1_TX1_P)
/CM5/HDMI1_D2_N: Module302.148 (HDMI1_TX2_N)
/CM5/HDMI1_D2_P: Module302.146 (HDMI1_TX2_P)
/CM5/HDMI1_HOTPLUG: Module302.143 (HDMI1_HOTPLUG)
/CM5/HDMI1_SCL: Module302.147 (HDMI1_SCL)
/CM5/HDMI1_SDA: Module302.145 (HDMI1_SDA)
/CM5/HDMI_PI.HDMI0_CEC: Module302.151 (HDMI0_CEC); also elsewhere on the board
/CM5/HDMI_PI.HDMI0_CK_N: Module302.190 (HDMI0_CLK_N); also elsewhere on the board
/CM5/HDMI_PI.HDMI0_CK_P: Module302.188 (HDMI0_CLK_P); also elsewhere on the board
/CM5/HDMI_PI.HDMI0_D0_N: Module302.184 (HDMI0_TX0_N); also elsewhere on the board
/CM5/HDMI_PI.HDMI0_D0_P: Module302.182 (HDMI0_TX0_P); also elsewhere on the board
/CM5/HDMI_PI.HDMI0_D1_N: Module302.178 (HDMI0_TX1_N); also elsewhere on the board
/CM5/HDMI_PI.HDMI0_D1_P: Module302.176 (HDMI0_TX1_P); also elsewhere on the board
/CM5/HDMI_PI.HDMI0_D2_N: Module302.172 (HDMI0_TX2_N); also elsewhere on the board
/CM5/HDMI_PI.HDMI0_D2_P: Module302.170 (HDMI0_TX2_P); also elsewhere on the board
/CM5/HDMI_PI.HDMI0_HOTPLUG: Module302.153 (HDMI0_HOTPLUG); also elsewhere on the board
/CM5/HDMI_PI.HDMI0_SCL: Module302.200 (HDMI0_SCL); also elsewhere on the board
/CM5/HDMI_PI.HDMI0_SDA: Module302.199 (HDMI0_SDA); also elsewhere on the board
/CM5/ID_SC: Module301.35 (ID_SC)
/CM5/ID_SD: Module301.36 (ID_SD)
/CM5/PCIE_CLK_N: Module302.112 (PCIe_CLK_N)
/CM5/PCIE_CLK_P: Module302.110 (PCIe_CLK_P)
/CM5/PCIE_PWR_EN: Module302.106 (PCIE_PWR_EN)
/CM5/PCIE_RX_N: Module302.118 (PCIe_RX_N)
/CM5/PCIE_RX_P: Module302.116 (PCIe_RX_P)
/CM5/PCIE_TX_N: Module302.124 (PCIe_TX_N)
/CM5/PCIE_TX_P: Module302.122 (PCIe_TX_P)
/CM5/PCIE_nCLKREQ: Module302.102 (PCIe_nCLKREQ)
/CM5/PCIE_nRST: Module302.109 (PCIe_nRST)
/CM5/PCIE_nWAKE: Module302.104 (PCIE_nWAKE)
/CM5/PI_nLED_PWR: Module301.95 (LED_nPWR); also elsewhere on the board
/CM5/PWM: Module301.19 (FAN_PWM); also elsewhere on the board
/CM5/PWR_BUT: Module301.92 (PWR_BUT); also elsewhere on the board
/CM5/SD_CLK: Module301.57 (SD_CLK)
/CM5/SD_CMD: Module301.62 (SD_CMD)
/CM5/SD_DAT0: Module301.63 (SD_DAT0)
/CM5/SD_DAT1: Module301.67 (SD_DAT1)
/CM5/SD_DAT2: Module301.69 (SD_DAT2)
/CM5/SD_DAT3: Module301.61 (SD_DAT3)
/CM5/SD_PWR_ON: Module301.75 (SD_PWR_ON)
/CM5/SYNC_OUT: Module301.18 (Ethernet_SYNC_OUT(3.3v))
/CM5/TACHO: Module301.16 (FAN_TACHO); also elsewhere on the board
/CM5/USB2P.D_N: Module302.136 (USB3-0-D_N); also elsewhere on the board
/CM5/USB2P.D_P: Module302.134 (USB3-0-D_P); also elsewhere on the board
/CM5/USB3-0-RX_N: Module302.128 (USB3-0-RX_N)
/CM5/USB3-0-RX_P: Module302.130 (USB3-0-RX_P)
/CM5/USB3-0-TX_N: Module302.140 (USB3-0-TX_N)
/CM5/USB3-0-TX_P: Module302.142 (USB3-0-TX_P)
/CM5/USB3-1-D_N: Module302.165 (USB3-1-D_N)
/CM5/USB3-1-D_P: Module302.163 (USB3-1-D_P)
/CM5/USB3-1-RX_N: Module302.157 (USB3-1-RX_N)
/CM5/USB3-1-RX_P: Module302.159 (USB3-1-RX_P)
/CM5/USB3-1-TX_N: Module302.169 (USB3-1-TX_N)
/CM5/USB3-1-TX_P: Module302.171 (USB3-1-TX_P)
/CM5/USBOTG_ID: Module302.101 (USB_OTG_ID)
/CM5/VBAT: Module301.76 (VBAT)
/CM5/VBUS_EN: Module302.111 (VBUS_EN); also elsewhere on the board
/CM5/WL_nDis: J301.1, Module301.89 (WiFi_nDisable)
/CM5/nLED_ACTIVITY: Module301.21 (LED_nACT); also elsewhere on the board
/CM5/nLED_SPEED_100_1000: Module301.17 (Ethernet_nLED2(3.3v)); also elsewhere on the board
/CM5/nRPIBOOT: Module301.93 (nRPIBOOT)
/LoRaWAN/UART2_RX: Module301.54 (GPIO4); also elsewhere on the board
/LoRaWAN/UART2_TX: Module301.34 (GPIO5); also elsewhere on the board
/SCL: Module301.80 (SCL0); also elsewhere on the board
/SDA: Module301.82 (SDA0); also elsewhere on the board
/USB_C.D_N: Module302.103 (USB2_N); also elsewhere on the board
/USB_C.D_P: Module302.105 (USB2_P); also elsewhere on the board
GND: J301.2, Module301.1 (GND), Module301.2 (GND), Module301.7 (GND), Module301.8 (GND), Module301.13 (GND), Module301.14 (GND), Module301.22 (GND), Module301.23 (GND), Module301.32 (GND), Module301.33 (GND), Module301.42 (GND), Module301.43 (GND), Module301.52 (GND), Module301.53 (GND), Module301.59 (GND), Module301.60 (GND), Module301.65 (GND), Module301.66 (GND), Module301.71 (GND), Module301.74 (GND), Module301.98 (GND), Module302.107 (GND), Module302.108 (GND), Module302.113 (GND), Module302.114 (GND), Module302.119 (GND), Module302.120 (GND), Module302.125 (GND), Module302.126 (GND), Module302.131 (GND), Module302.132 (GND), Module302.137 (GND), Module302.138 (GND), Module302.144 (GND), Module302.150 (GND), Module302.155 (GND), Module302.156 (GND), Module302.161 (GND), Module302.162 (GND), Module302.167 (GND), Module302.168 (GND), Module302.173 (GND), Module302.174 (GND), Module302.179 (GND), Module302.180 (GND), Module302.185 (GND), Module302.186 (GND), Module302.191 (GND), Module302.192 (GND), Module302.197 (GND), Module302.198 (GND); also elsewhere on the board

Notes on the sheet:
Not Fitted header
CM mechanicals
[CM5]

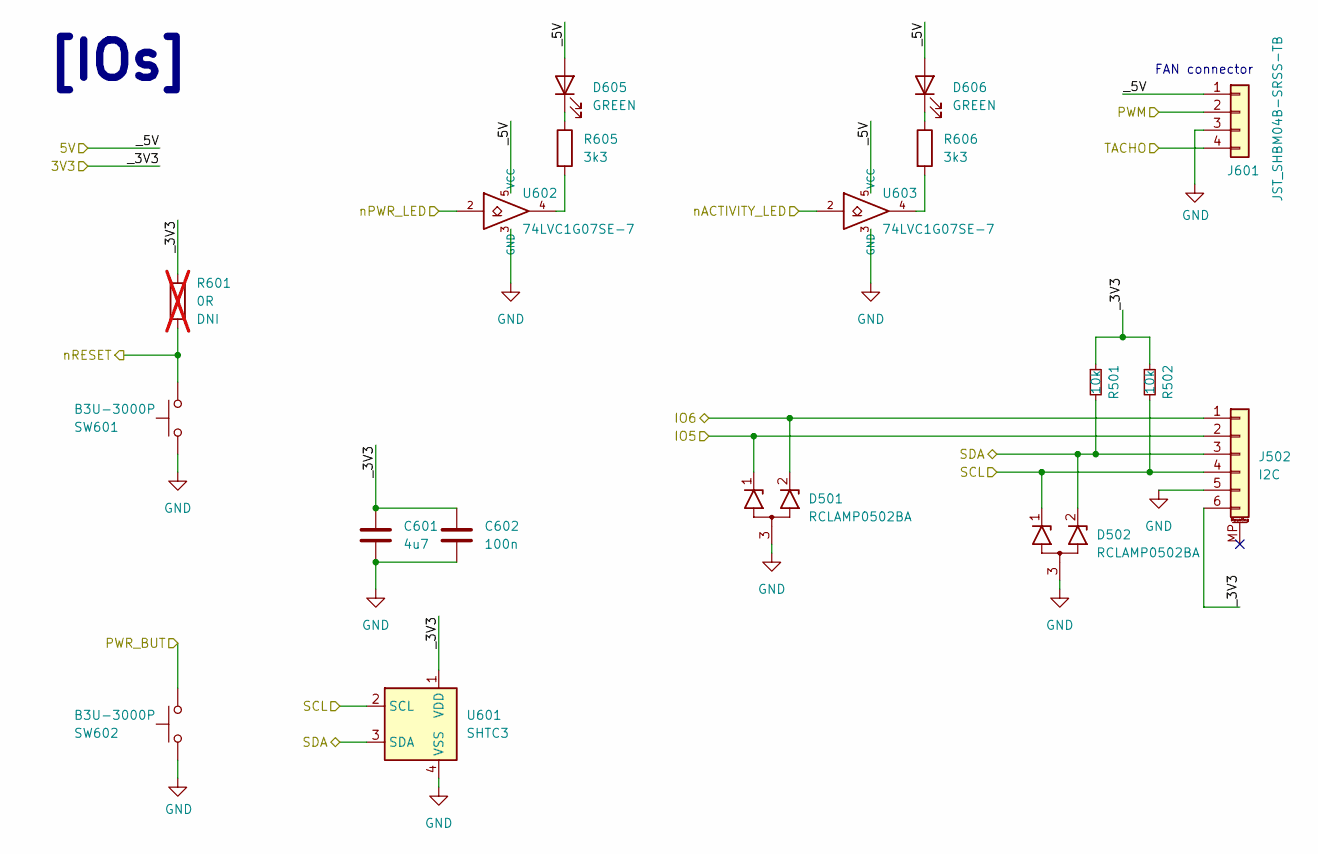
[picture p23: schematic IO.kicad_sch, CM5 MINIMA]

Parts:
C601: 4u7; C_0805_2012Metric; Part Description 4.7uF 10% 10V Ceramic Capacitor X7R 080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
C602: 100n; C_0402_1005Metric; Part Description 0.1uF 10% 16V Ceramic Capacitor X7R 040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
D501, D502: RCLAMP0502BA; SOT-416
D605, D606: GREEN; Led_Wurth_0603_side
J502: I2C; JST_GH_BM06B-GHS-TBT_1x06-1MP_P1.25mm_Vertical
J601: JST_SHBM04B-SRSS-TB; JST_SH_BM04B-SRSS-TB_1x04-1MP_P1.00mm_Vertical; Part Description 4 pin vertical 1mm pitch connector
R501, R502: 10k; R_0402_1005Metric
R601: 0R; R_0402_1005Metric; not fitted
R605, R606: 3k3; R_0402_1005Metric
SW601, SW602: B3U-3000P; SW_SPST_B3U-3100P-B
U601: SHTC3; Sensirion_DFN-4-1EP_2x2mm_P1mm_EP0.7x1.6mm
U602, U603: 74LVC1G07SE-7; SOT-353_SC-70-5; Part Description Buffer, Non-Inverting 1 Element 1 Bit p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

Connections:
+3V3: C601.1, C602.1, J502.6, R501.1, R502.1, R601.1, U601.1 (VDD); also elsewhere on the board
+5V: D605.2 (A), D606.2 (A), J601.1, U602.5 (VCC), U603.5 (VCC); also elsewhere on the board
/CM5/GLOBAL_EN: R601.2, SW601.1; also elsewhere on the board
/CM5/PI_nLED_PWR: U602.2; also elsewhere on the board
/CM5/PWM: J601.2; also elsewhere on the board
/CM5/PWR_BUT: SW602.1; also elsewhere on the board
/CM5/TACHO: J601.4; also elsewhere on the board
/CM5/nLED_ACTIVITY: U603.2; also elsewhere on the board
/IO/IO5: D501.1 (K1), J502.2
/IO/IO6: D501.2 (K2), J502.1
/SCL: D502.1 (K1), J502.4, R502.2, U601.2 (SCL); also elsewhere on the board
/SDA: D502.2 (K2), J502.3, R501.2, U601.3 (SDA); also elsewhere on the board
GND: C601.2, C602.2, D501.3 (A), D502.3 (A), J502.5, J601.3, SW601.2, SW602.2, U601.4 (VSS), U602.3 (GND), U603.3 (GND); also elsewhere on the board
unnamed: D605.1 (K), R605.1
unnamed: D606.1 (K), R606.1
unnamed: R605.2, U602.4
unnamed: R606.2, U603.4

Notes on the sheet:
[IOs]
FAN connector

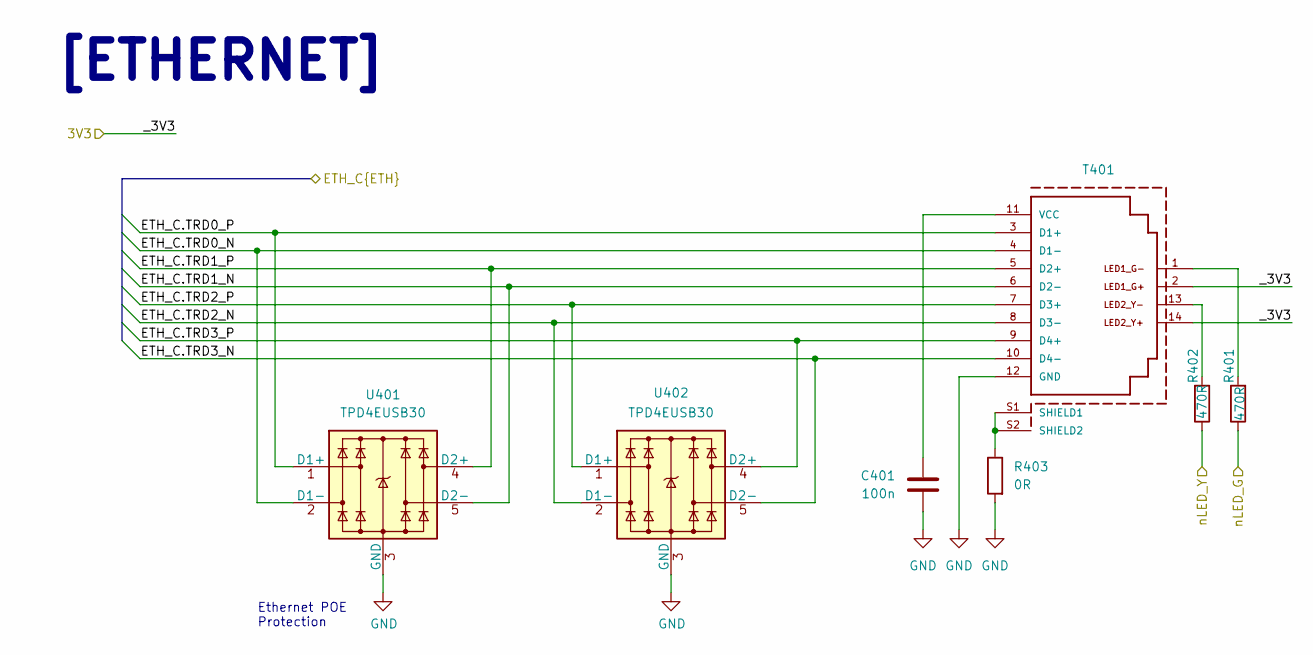
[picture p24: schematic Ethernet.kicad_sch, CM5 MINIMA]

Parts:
C401: 100n; C_0402_1005Metric; Part Description 0.1uF 10% 16V Ceramic Capacitor X7R 040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
R401, R402: 470R; R_0402_1005Metric
R403: 0R; R_0402_1005Metric
T401: 7498111120AR; PART-NUMBER 7498111120AR
U401, U402: TPD4EUSB30; USON-10_2.5x1.0mm_P0.5mm; Part Description Quad TVS diode for high speed signals (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

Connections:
+3V3: T401.2, T401.14; also elsewhere on the board
/CM5/ETH_PI.TRD0_N: T401.4 (D1-), U401.2 (D1-), U401.9; also elsewhere on the board
/CM5/ETH_PI.TRD0_P: T401.3 (D1+), U401.1 (D1+), U401.10; also elsewhere on the board
/CM5/ETH_PI.TRD1_N: T401.6 (D2-), U401.5 (D2-), U401.6; also elsewhere on the board
/CM5/ETH_PI.TRD1_P: T401.5 (D2+), U401.4 (D2+), U401.7; also elsewhere on the board
/CM5/ETH_PI.TRD2_N: T401.8 (D3-), U402.2 (D1-), U402.9; also elsewhere on the board
/CM5/ETH_PI.TRD2_P: T401.7 (D3+), U402.1 (D1+), U402.10; also elsewhere on the board
/CM5/ETH_PI.TRD3_N: T401.10 (D4-), U402.5 (D2-), U402.6; also elsewhere on the board
/CM5/ETH_PI.TRD3_P: T401.9 (D4+), U402.4 (D2+), U402.7; also elsewhere on the board
/CM5/ETH_nLED_ACTIVITY: R401.1; also elsewhere on the board
/CM5/nLED_SPEED_100_1000: R402.1; also elsewhere on the board
GND: C401.2, R403.2, T401.12 (GND), U401.3 (GND), U401.8 (GND), U402.3 (GND), U402.8 (GND); also elsewhere on the board
unnamed: R401.2, T401.1
unnamed: R402.2, T401.13
unnamed: R403.1, T401.S1 (SHIELD1), T401.S2 (SHIELD2)
unnamed: C401.1, T401.11 (VCC)

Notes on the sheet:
[ETHERNET]
Ethernet POE Protection

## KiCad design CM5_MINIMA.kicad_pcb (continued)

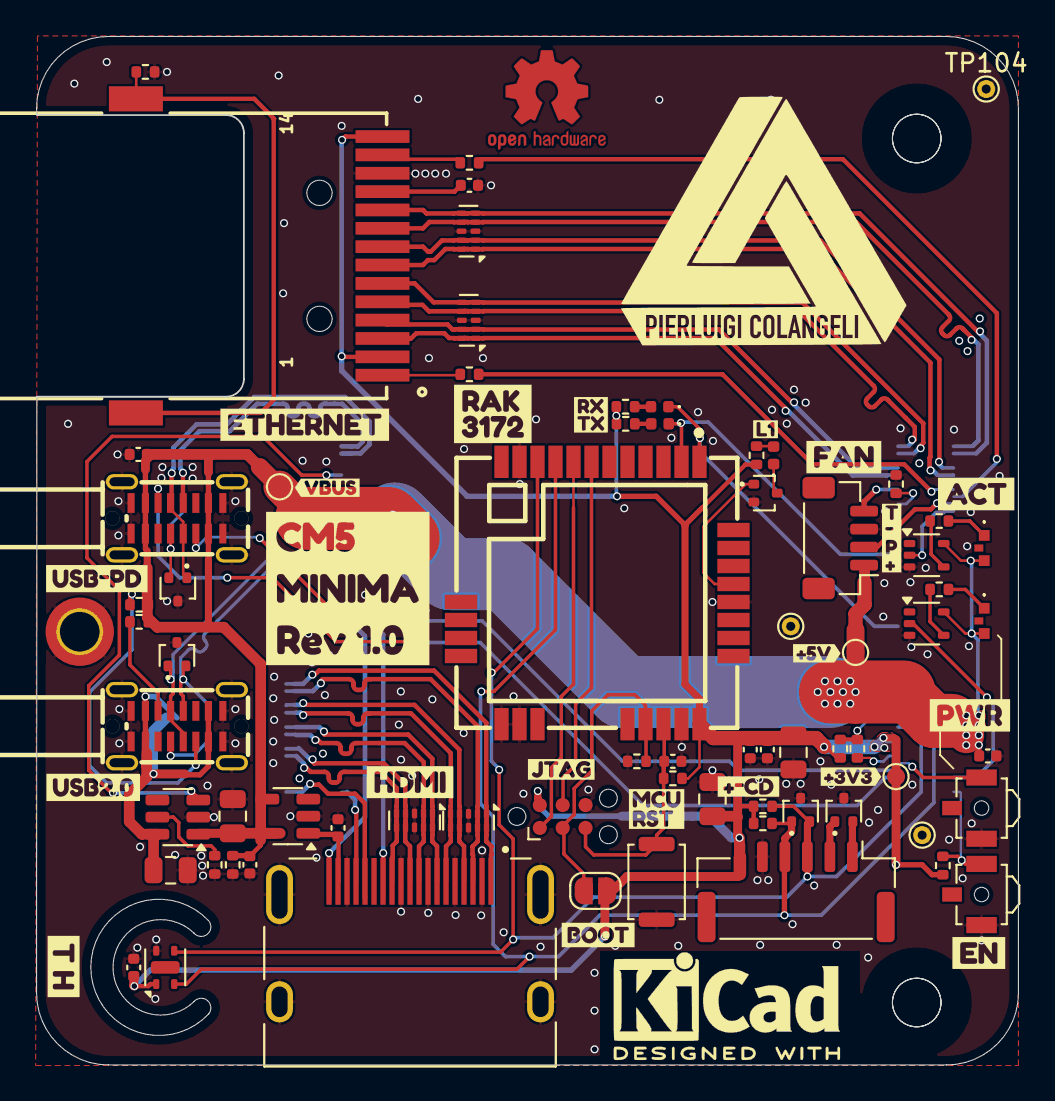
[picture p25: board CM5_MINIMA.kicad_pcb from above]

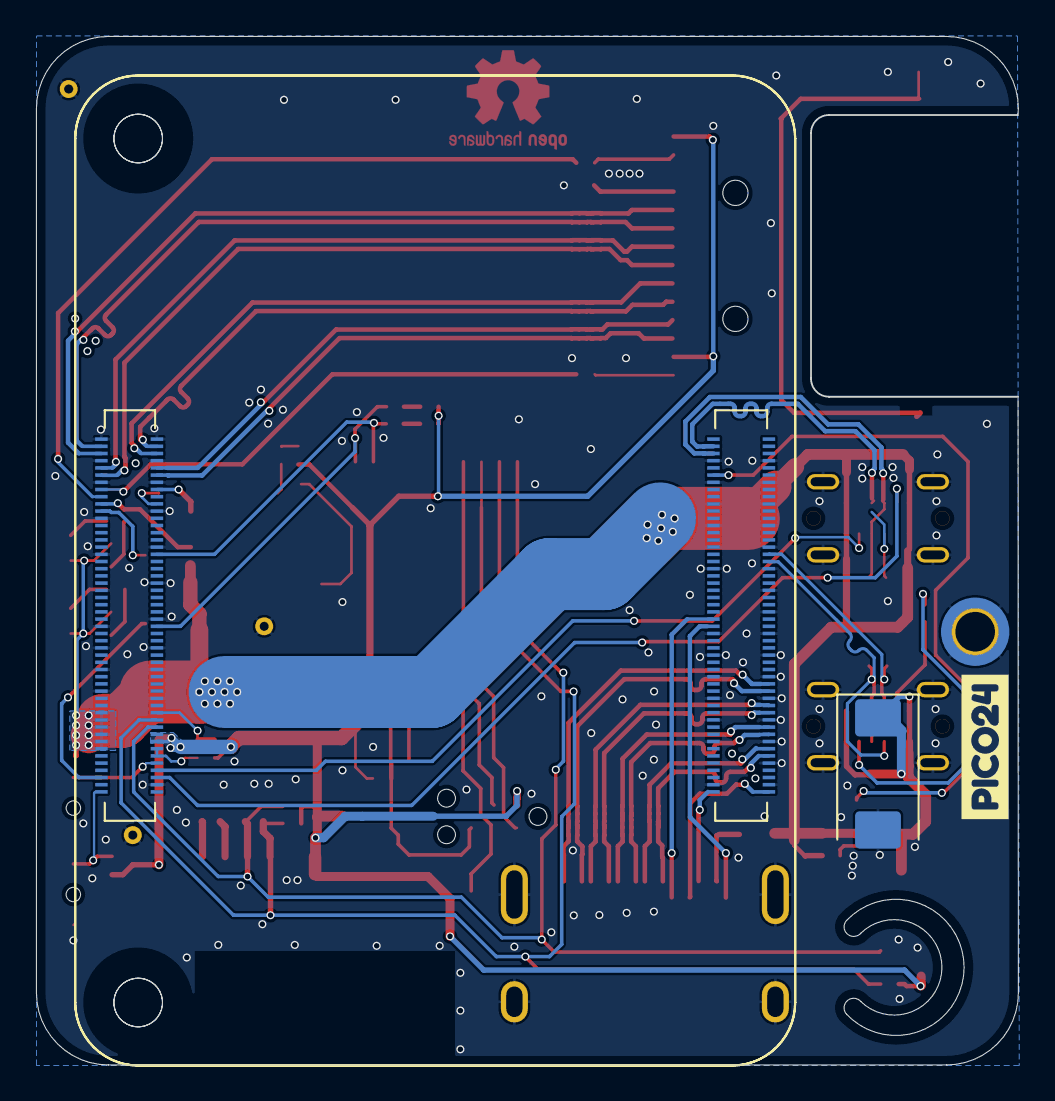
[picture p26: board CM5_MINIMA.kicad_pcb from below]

Board: 4 copper layers, 54.6 x 57.1 mm, 96 parts (4 on the bottom side), 69 nets.

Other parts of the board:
kibuzzard-675DA85E: G***; kibuzzard-675DA85E
kibuzzard-675DA838: G***; kibuzzard-675DA838
kibuzzard-675DA850: G***; kibuzzard-675DA850
kibuzzard-675DA866: G***; kibuzzard-675DA866
kibuzzard-675DB3C2: G***; kibuzzard-675DB3C2
kibuzzard-675DBE31: G***; kibuzzard-675DBE31
kibuzzard-675DBE43: G***; kibuzzard-675DBE43
kibuzzard-675DC2F1: G***; kibuzzard-675DC2F1
kibuzzard-675DCF7A: G***; kibuzzard-675DCF7A
kibuzzard-675DCF9A: G***; kibuzzard-675DCF9A
kibuzzard-675DF4E5: G***; kibuzzard-675DF4E5
kibuzzard-675EDCA4: G***; kibuzzard-675EDCA4
kibuzzard-675EDCB9: G***; kibuzzard-675EDCB9
kibuzzard-67601A65: G***; kibuzzard-67601A65
kibuzzard-67601AC8: G***; kibuzzard-67601AC8
kibuzzard-67601C98: G***; kibuzzard-67601C98
kibuzzard-67602DFF: G***; kibuzzard-67602DFF
kibuzzard-676020C0: G***; kibuzzard-676020C0
kibuzzard-676020D8: G***; kibuzzard-676020D8
kibuzzard-676020F6: G***; kibuzzard-676020F6
kibuzzard-67601717: G***; kibuzzard-67601717
kibuzzard-67602076: G***; kibuzzard-67602076

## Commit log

2024-12-17 DRC ok
    [CM5_MINIMA.kicad_pcb]
2024-12-17 round slot TH
    [CM5_MINIMA.kicad_pcb]
2024-12-17 changed switch on HDMI
    [CM5_CB-CuBottom.gbr, CM5_CB-CuIn1.gbr, CM5_CB-CuIn2.gbr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]
2024-12-17 bom finished
    [CM5_MINIMA-CuBottom.gbr, CM5_MINIMA-CuIn1.gbr, CM5_MINIMA-CuIn2.gbr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]
2024-12-17 fix problem ethernet connector
    [CM5_MINIMA-CuBottom.gbr, CM5_MINIMA-CuIn1.gbr, CM5_MINIMA-CuIn2.gbr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]
2024-12-17 production files added
    [CM5_MINIMA-CuBottom.gbr, CM5_MINIMA-CuIn1.gbr, CM5_MINIMA-CuIn2.gbr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]
2024-12-21 diff pairs redesigned for pcbway capabilities
    [CM5_MINIMA.kicad_pcb]
2024-12-22 impedance PCBway
    [CM5_MINIMA.kicad_pcb]
2025-01-10 RAK3172 from UART0_IR to UART3
    [CM5.kicad_sch, CM5_MINIMA.kicad_sch]
2025-01-10 RAK to UART2 PCB
    [CM5_MINIMA.kicad_pcb]
2025-01-10 updated PCBWay fab files
2025-01-10 PDF schematics updated

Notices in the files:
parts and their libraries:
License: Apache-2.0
